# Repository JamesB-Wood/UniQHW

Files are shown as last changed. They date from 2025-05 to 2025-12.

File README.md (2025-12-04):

# UniQHW

The hardware repository for UQ Phone (UniQ)
The Corresponding software component can be found [https://github.com/Benksur/UniQOS](https://github.com/Benksur/UniQOS)

## About

**Supervised by:** Professor Pauline Pounds  
**Institution:** University of Queensland
<div align="center">

### UQ Phone Team (Year 1 - 2025)

| Name | Role |
|---|---|
| **Ty Behnke** | Firmware Design |
| **James Wood** | Hardware Design |
| **Caiyan Jin** | UI/UX Design |
</div>

Any Questions about the PCB and Schematics please direct them to [james.brian.wood@gmail.com](james.brian.wood@gmail.com)

## Production

The V0.2.0 PCB's must be made with the following specifications from JLCPCB

### Main PCB

This 6-Layer PCB must be made with the following

- Via Covering:	Epoxy Filled & Capped
- Min via hole size/diameter:	0.2mm/(0.3/0.35mm)

The following are also required if meeting the full size specifications of UniQ

- PCB Thickness:	0.8mm

Production versions should also be made with the following (Dependant on desired finish)

- Surface Finish:	ENIG Gold Thickness: 2U"
- PCB Color:	Black
- Silkscreen:	White

### Secondary PCB (Cellular Board)

This 4-Layer PCB must be made with the following

- PCB Thickness:	0.6mm
- Via Covering:	Epoxy Filled & Capped
- Min via hole size/diameter:	0.2mm/(0.3/0.35mm)
- Specify Stackup:	yes JLC04061H-2116

If Either the thickness or stackup is to change this boards traces should be redesigned for 50Ohm Impedance 

Production versions should also be made with the following (Dependant on desired finish)

- Surface Finish:	ENIG Gold Thickness: 2U"
- PCB Color:	Black
- Silkscreen:	White

## Current Issues And Improvements

The V0.2.0 PCB currently suffers from several issues which should be rectified on later versions:

- Batter Connector Location: move so it can be inserted and removed indpendantly of the secondary PCB
- SD/SIM Socket: Tie 3.3v SD card rail to insertion detection to prevent hot-plugging
- Debug Pads: Consider moving to provide easier access without interferance from screen
- Soft Power: Add soft power switch for more agressive power-off functionality and safer power-downs

The following may also be investigated for benefit 
- Improve Display: Ideally Display utilises a parellel interface, this needs more investigation
- Audio Volume: Current speaker is quiet, this should be investigated further to see if this can be remediated in firmware first
- USB Support: Add USB data connectivity to the device for file transfer or programming, this may resolve debug pad issues
- BT Audio: this poses significant challenges, although may be worth while, investigate further

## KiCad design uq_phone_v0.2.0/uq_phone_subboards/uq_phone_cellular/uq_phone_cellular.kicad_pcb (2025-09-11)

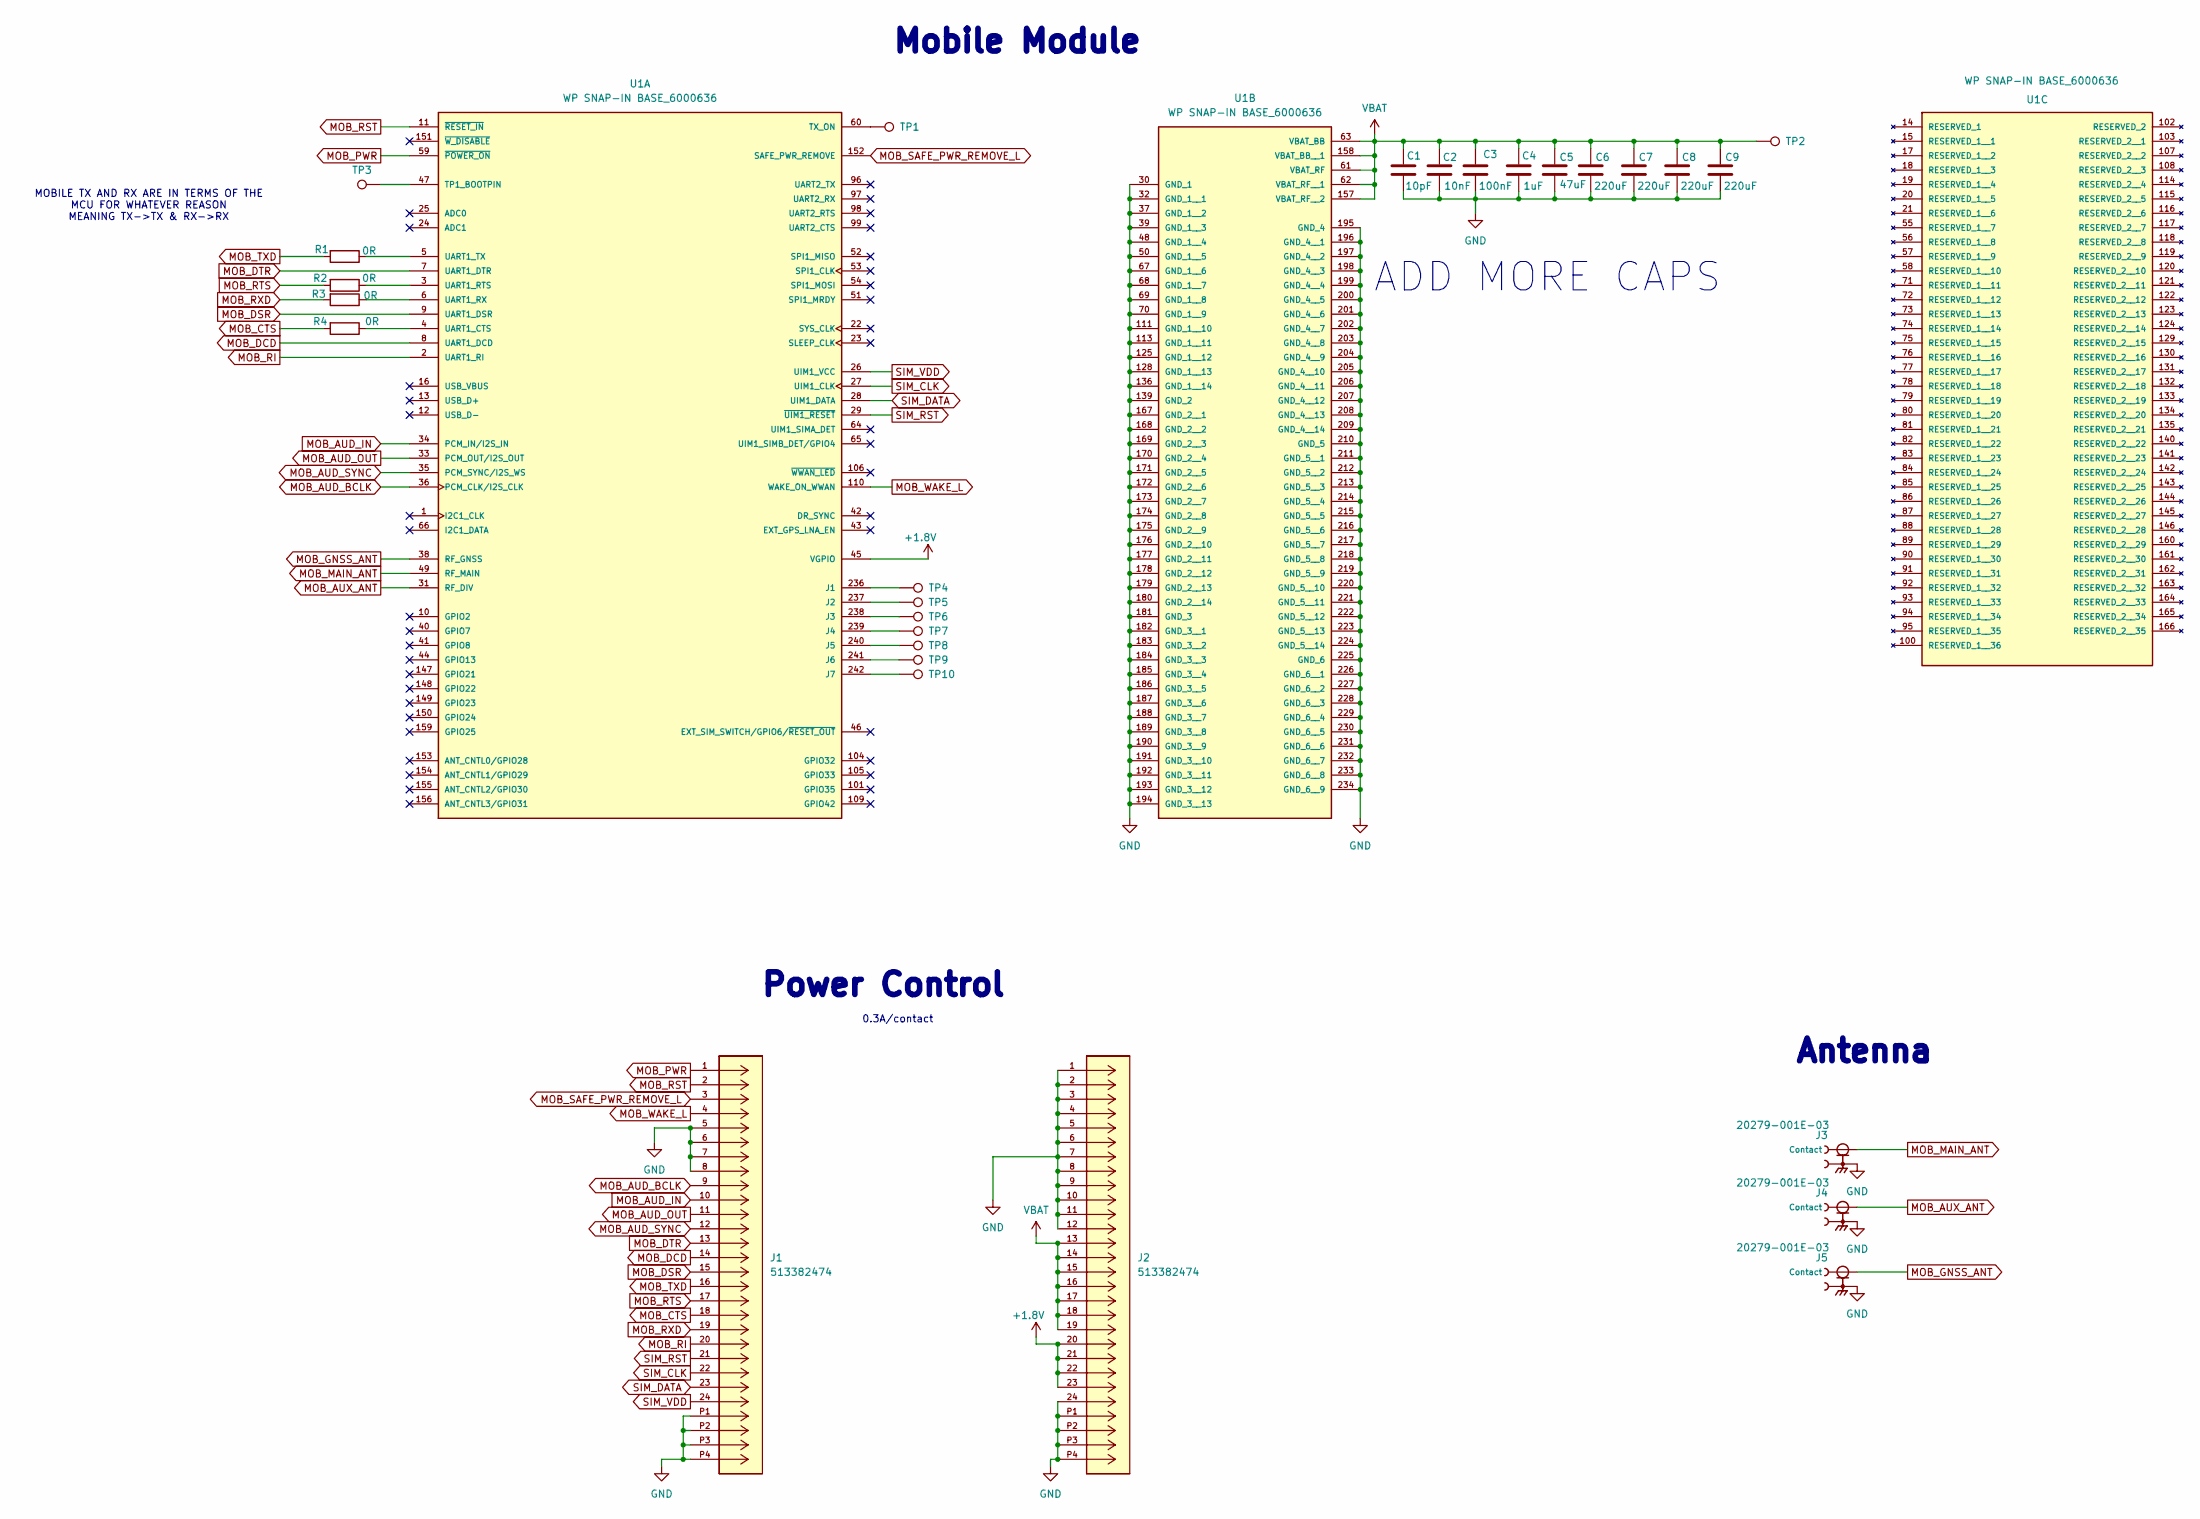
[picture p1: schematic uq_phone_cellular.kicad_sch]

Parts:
C1: 10pF; C_0402_1005Metric; LCSC PN C2168222
C2: 10nF; C_0402_1005Metric; LCSC PN C15195
C3: 100nF; C_0201_0603Metric; LCSC PN C160831
C4: 1uF; C_0201_0603Metric; LCSC PN C53067
C5: 47uF; C_0805_2012Metric; LCSC PN C109461
C6, C7, C8, C9: 220uF; C_1206_3216Metric; LCSC PN C412252
J1, J2: 513382474; CON_513382474; MANUFACTURER_PART_NUMBER 513382474; DigiKey_Part_Number WM8960TR-ND
J3, J4, J5: 20279-001E-03; IPEX_20279-001E-03; PARTREV 32; LCSC PN C36499136
R1, R2, R3, R4: 0R; R_0402_1005Metric; LCSC PN C60485
TP1, TP2, TP3, TP4, TP5, TP6, TP7, TP8, TP9, TP10: TestPoint; TestPoint_Pad_D1.5mm
U1: WP SNAP-IN BASE_6000636; XCVR_RC7620_1104625; PARTREV 12

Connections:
+1.8V: J2.20, J2.21, J2.22, J2.23, U1.45 (VGPIO)
GND: C1.2, C2.2, C3.2, C4.2, C5.2, C6.2, C7.2, C8.2, C9.2, J1.5, J1.6, J1.7, J1.8, J1.P1, J1.P2, J1.P3, J1.P4, J2.1, J2.2, J2.3, J2.4, J2.5, J2.6, J2.7, J2.8, J2.9, J2.10, J2.11, J2.12, J2.24, J2.P1, J2.P2, J2.P3, J2.P4, J3.2, J4.2, J5.2, U1.30 (GND_1), U1.32 (GND_1__1), U1.37 (GND_1__2), U1.39 (GND_1__3), U1.48 (GND_1__4), U1.50 (GND_1__5), U1.67 (GND_1__6), U1.68 (GND_1__7), U1.69 (GND_1__8), U1.70 (GND_1__9), U1.111 (GND_1__10), U1.113 (GND_1__11), U1.125 (GND_1__12), U1.128 (GND_1__13), U1.136 (GND_1__14), U1.139 (GND_2), U1.167 (GND_2__1), U1.168 (GND_2__2), U1.169 (GND_2__3), U1.170 (GND_2__4), U1.171 (GND_2__5), U1.172 (GND_2__6), U1.173 (GND_2__7), U1.174 (GND_2__8), U1.175 (GND_2__9), U1.176 (GND_2__10), U1.177 (GND_2__11), U1.178 (GND_2__12), U1.179 (GND_2__13), U1.180 (GND_2__14), U1.181 (GND_3), U1.182 (GND_3__1), U1.183 (GND_3__2), U1.184 (GND_3__3), U1.185 (GND_3__4), U1.186 (GND_3__5), U1.187 (GND_3__6), U1.188 (GND_3__7), U1.189 (GND_3__8), U1.190 (GND_3__9), U1.191 (GND_3__10), U1.192 (GND_3__11), U1.193 (GND_3__12), U1.194 (GND_3__13), U1.195 (GND_4), U1.196 (GND_4__1), U1.197 (GND_4__2), U1.198 (GND_4__3), U1.199 (GND_4__4), U1.200 (GND_4__5), U1.201 (GND_4__6), U1.202 (GND_4__7), U1.203 (GND_4__8), U1.204 (GND_4__9), U1.205 (GND_4__10), U1.206 (GND_4__11), U1.207 (GND_4__12), U1.208 (GND_4__13), U1.209 (GND_4__14), U1.210 (GND_5), U1.211 (GND_5__1), U1.212 (GND_5__2), U1.213 (GND_5__3), U1.214 (GND_5__4), U1.215 (GND_5__5), U1.216 (GND_5__6), U1.217 (GND_5__7), U1.218 (GND_5__8), U1.219 (GND_5__9), U1.220 (GND_5__10), U1.221 (GND_5__11), U1.222 (GND_5__12), U1.223 (GND_5__13), U1.224 (GND_5__14), U1.225 (GND_6), U1.226 (GND_6__1), U1.227 (GND_6__2), U1.228 (GND_6__3), U1.229 (GND_6__4), U1.230 (GND_6__5), U1.231 (GND_6__6), U1.232 (GND_6__7), U1.233 (GND_6__8), U1.234 (GND_6__9)
MOB_AUD_BCLK: J1.9, U1.36 (PCM_CLK/I2S_CLK)
MOB_AUD_IN: J1.10, U1.34 (PCM_IN/I2S_IN)
MOB_AUD_OUT: J1.11, U1.33 (PCM_OUT/I2S_OUT)
MOB_AUD_SYNC: J1.12, U1.35 (PCM_SYNC/I2S_WS)
MOB_AUX_ANT: J4.1 (Contact), U1.31 (RF_DIV)
MOB_CTS: J1.18, R4.2
MOB_DCD: J1.14, U1.8 (UART1_DCD)
MOB_DSR: J1.15, U1.9 (UART1_DSR)
MOB_DTR: J1.13, U1.7 (UART1_DTR)
MOB_GNSS_ANT: J5.1 (Contact), U1.38 (RF_GNSS)
MOB_MAIN_ANT: J3.1 (Contact), U1.49 (RF_MAIN)
MOB_PWR: J1.1, U1.59 (~POWER_ON)
MOB_RI: J1.20, U1.2 (UART1_RI)
MOB_RST: J1.2, U1.11 (~RESET_IN)
MOB_RTS: J1.17, R2.2
MOB_RXD: J1.19, R3.2
MOB_SAFE_PWR_REMOVE_L: J1.3, U1.152 (SAFE_PWR_REMOVE)
MOB_TXD: J1.16, R1.2
MOB_WAKE_L: J1.4, U1.110 (WAKE_ON_WWAN)
unnamed: TP4.1, U1.236 (J1)
unnamed: TP5.1, U1.237 (J2)
unnamed: TP6.1, U1.238 (J3)
unnamed: TP7.1, U1.239 (J4)
unnamed: TP8.1, U1.240 (J5)
unnamed: TP9.1, U1.241 (J6)
unnamed: TP10.1, U1.242 (J7)
unnamed: TP3.1, U1.47 (TP1_BOOTPIN)
unnamed: TP1.1, U1.60 (TX_ON)
unnamed: R4.1, U1.4 (UART1_CTS)
unnamed: R2.1, U1.3 (UART1_RTS)
unnamed: R3.1, U1.6 (UART1_RX)
unnamed: R1.1, U1.5 (UART1_TX)
SIM_CLK: J1.22, U1.27 (UIM1_CLK)
SIM_DATA: J1.23, U1.28 (UIM1_DATA)
SIM_RST: J1.21, U1.29 (~UIM1_RESET)
SIM_VDD: J1.24, U1.26 (UIM1_VCC)
VBAT: C1.1, C2.1, C3.1, C4.1, C5.1, C6.1, C7.1, C8.1, C9.1, J2.13, J2.14, J2.15, J2.16, J2.17, J2.18, J2.19, TP2.1, U1.61 (VBAT_RF), U1.62 (VBAT_RF__1), U1.63 (VBAT_BB), U1.157 (VBAT_RF__2), U1.158 (VBAT_BB__1)

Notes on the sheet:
ADD MORE CAPS
Antenna
Power Control
MOBILE TX AND RX ARE IN TERMS OF THE MCU FOR WHATEVER REASON MEANING TX->TX & RX->RX
0.3A/contact
Mobile Module

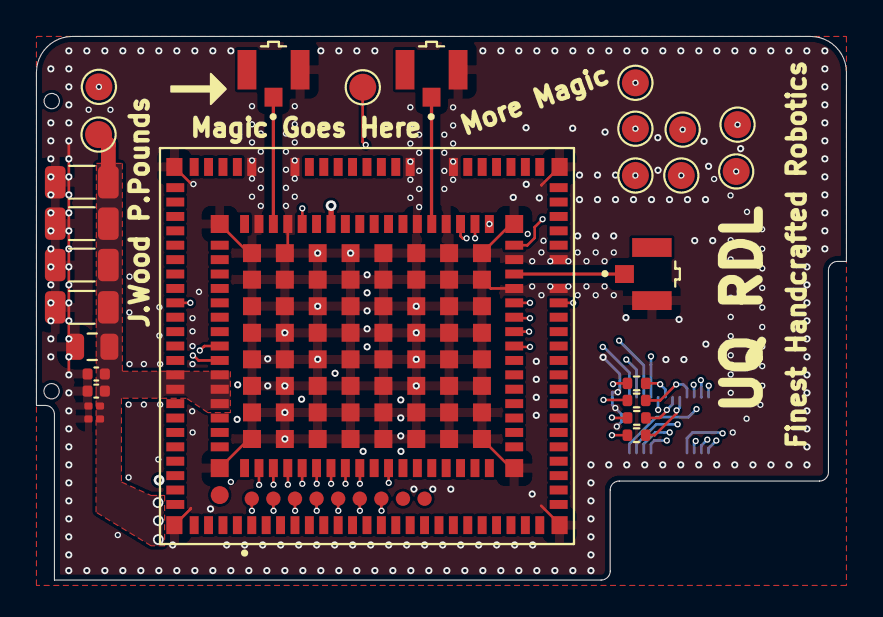
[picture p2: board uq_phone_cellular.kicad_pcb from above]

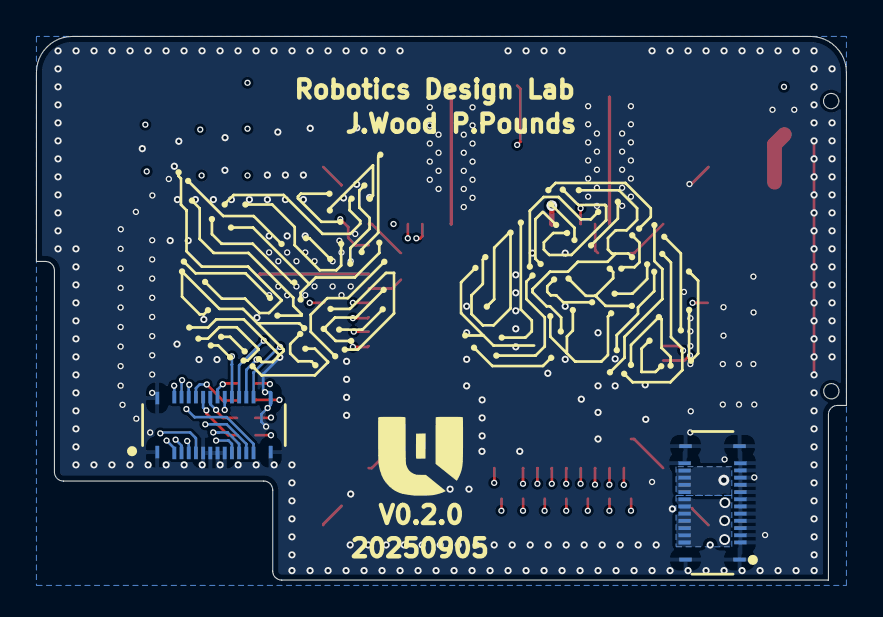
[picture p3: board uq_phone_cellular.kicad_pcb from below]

Board: 4 copper layers, 45.0 x 30.2 mm, 29 parts (2 on the bottom side), 39 nets.

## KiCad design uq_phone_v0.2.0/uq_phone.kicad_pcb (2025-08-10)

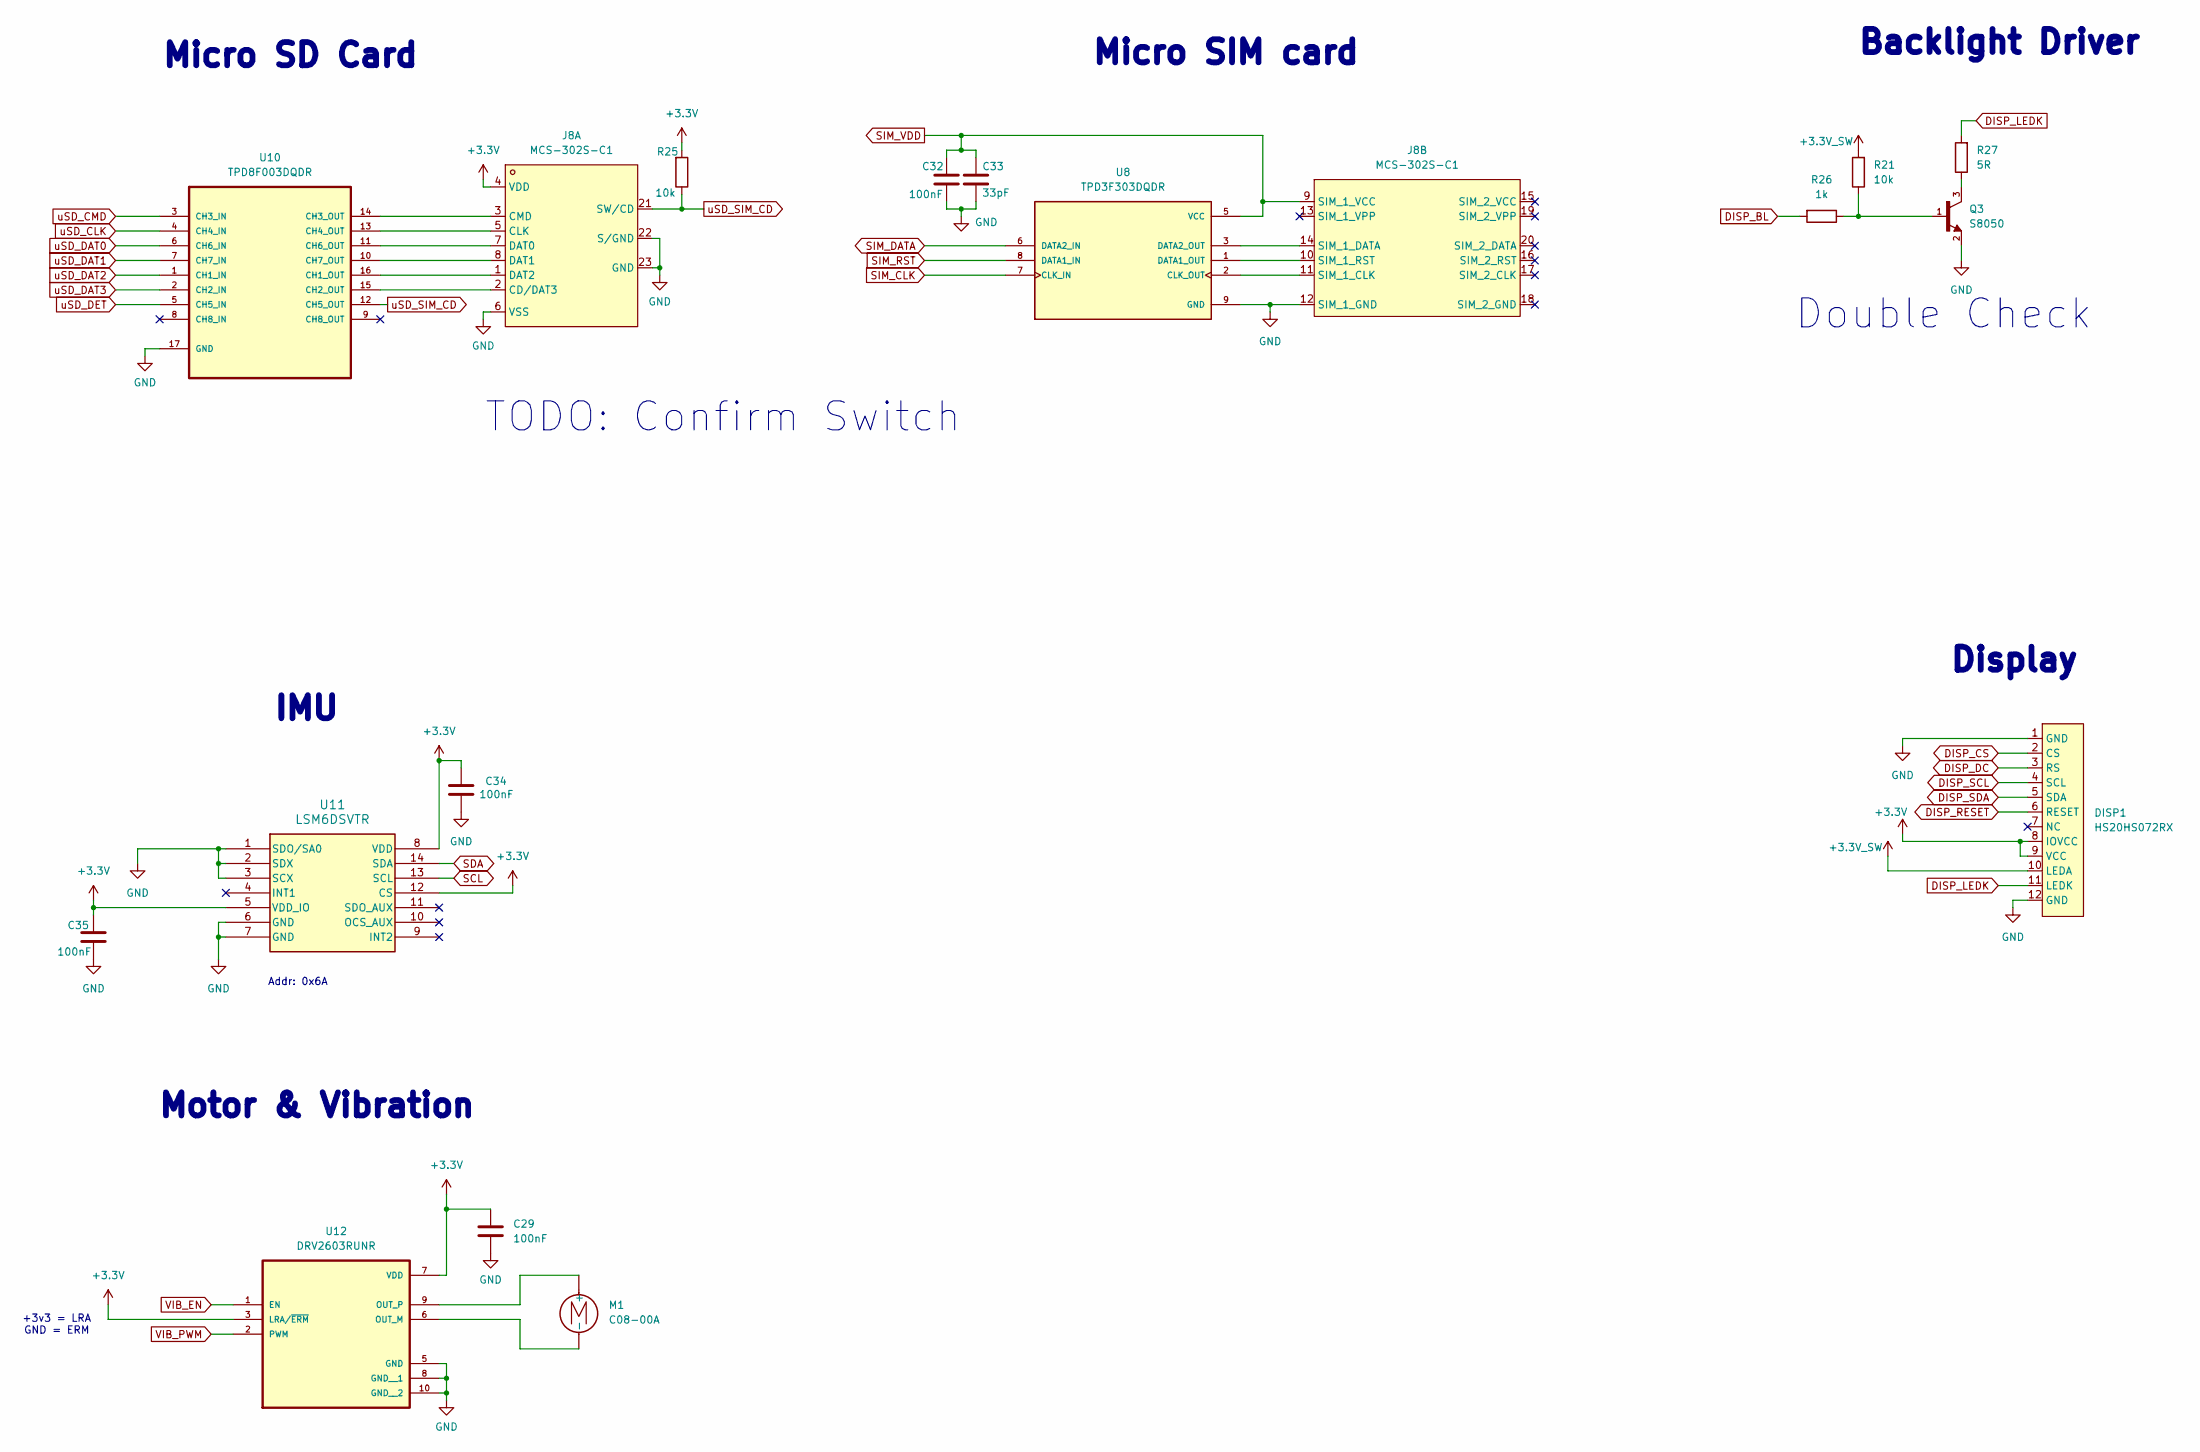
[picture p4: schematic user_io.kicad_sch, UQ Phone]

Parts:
C29, C32, C34, C35: 100nF; C_0201_0603Metric; LCSC PN C160831
C33: 33pF; C_0402_1005Metric; LCSC PN C70465
DISP1: HS20HS072RX; Display
J8: MCS-302S-C1; SIM-SMD_MCS-302S-C1; Manufacturer Part MCS-302S-C1; LCSC Part Name 卡托式 NanoSIM卡 卡座
M1: C08-00A; Motor_8mm
Q3: S8050; SOT-23; LCSC PN C916390
R21, R25: 10k; R_0201_0603Metric; LCSC PN C106225
R26: 1k; R_0402_1005Metric; LCSC PN C5455561
R27: 5R; R_0402_1005Metric; LCSC PN C25128
U8: TPD3F303DQDR; SON40P170X135X80-9N; PARTREV A; DigiKey_Part_Number 296-28300-2-ND
U10: TPD8F003DQDR; SON40P135X330X80-17N; MPN TPD8F003DQDR; DigiKey_Part_Number 296-25803-2-ND
U11: LSM6DSVTR; LGA14-L_2P59X3P1X0P5_STM
U12: DRV2603RUNR; QFN50P200X200X80-10N; PARTREV C; DigiKey_Part_Number 296-30613-2-ND

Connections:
+3.3V: C29.1, C34.1, C35.1, DISP1.8 (IOVCC), DISP1.9 (VCC), J8.4 (VDD), R25.2, U11.5 (VDD_IO), U11.8 (VDD), U11.12 (CS), U12.3 (LRA/~ERM), U12.7 (VDD); also elsewhere on the board
+3.3V_SW: DISP1.10 (LEDA), R21.2; also elsewhere on the board
DISP_BL: R26.2; also elsewhere on the board
DISP_CS: DISP1.2 (CS); also elsewhere on the board
DISP_DC: DISP1.3 (RS); also elsewhere on the board
DISP_LEDK: DISP1.11 (LEDK), R27.2
DISP_RESET: DISP1.6 (RESET); also elsewhere on the board
DISP_SCL: DISP1.4 (SCL); also elsewhere on the board
DISP_SDA: DISP1.5 (SDA); also elsewhere on the board
GND: C29.2, C32.2, C33.2, C34.2, C35.2, DISP1.1 (GND), DISP1.12 (GND), J8.6 (VSS), J8.12 (SIM_1_GND), J8.22 (S/GND), J8.23 (GND), Q3.2, U8.9 (GND), U10.17 (GND), U11.1 (SDO/SA0), U11.2 (SDX), U11.3 (SCX), U11.6 (GND), U11.7 (GND), U12.5 (GND), U12.8 (GND__1), U12.10 (GND__2); also elsewhere on the board
unnamed: J8.2 (CD/DAT3), U10.15 (CH2_OUT)
unnamed: J8.5 (CLK), U10.13 (CH4_OUT)
unnamed: J8.3 (CMD), U10.14 (CH3_OUT)
unnamed: J8.7 (DAT0), U10.11 (CH6_OUT)
unnamed: J8.8 (DAT1), U10.10 (CH7_OUT)
unnamed: J8.1 (DAT2), U10.16 (CH1_OUT)
unnamed: J8.11 (SIM_1_CLK), U8.2 (CLK_OUT)
unnamed: J8.14 (SIM_1_DATA), U8.3 (DATA2_OUT)
unnamed: J8.10 (SIM_1_RST), U8.1 (DATA1_OUT)
unnamed: M1.1 (+), U12.9 (OUT_P)
unnamed: M1.2 (-), U12.6 (OUT_M)
unnamed: Q3.1, R21.1, R26.1
unnamed: Q3.3, R27.1
SCL: U11.13 (SCL); also elsewhere on the board
SDA: U11.14 (SDA); also elsewhere on the board
SIM_CLK: U8.7 (CLK_IN); also elsewhere on the board
SIM_DATA: U8.6 (DATA2_IN); also elsewhere on the board
SIM_RST: U8.8 (DATA1_IN); also elsewhere on the board
SIM_VDD: C32.1, C33.1, J8.9 (SIM_1_VCC), U8.5 (VCC); also elsewhere on the board
VIB_EN: U12.1 (EN); also elsewhere on the board
VIB_PWM: U12.2 (PWM); also elsewhere on the board
uSD_CLK: U10.4 (CH4_IN); also elsewhere on the board
uSD_CMD: U10.3 (CH3_IN); also elsewhere on the board
uSD_DAT0: U10.6 (CH6_IN); also elsewhere on the board
uSD_DAT1: U10.7 (CH7_IN); also elsewhere on the board
uSD_DAT2: U10.1 (CH1_IN); also elsewhere on the board
uSD_DAT3: U10.2 (CH2_IN); also elsewhere on the board
uSD_DET: U10.5 (CH5_IN); also elsewhere on the board
uSD_SIM_CD: J8.21 (SW/CD), R25.1, U10.12 (CH5_OUT)

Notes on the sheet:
Motor & Vibration
Display
IMU
Backlight Driver
Double Check
Micro SIM card
TODO: Confirm Switch
Micro SD Card
+3v3 = LRA GND = ERM
Addr: 0x6A

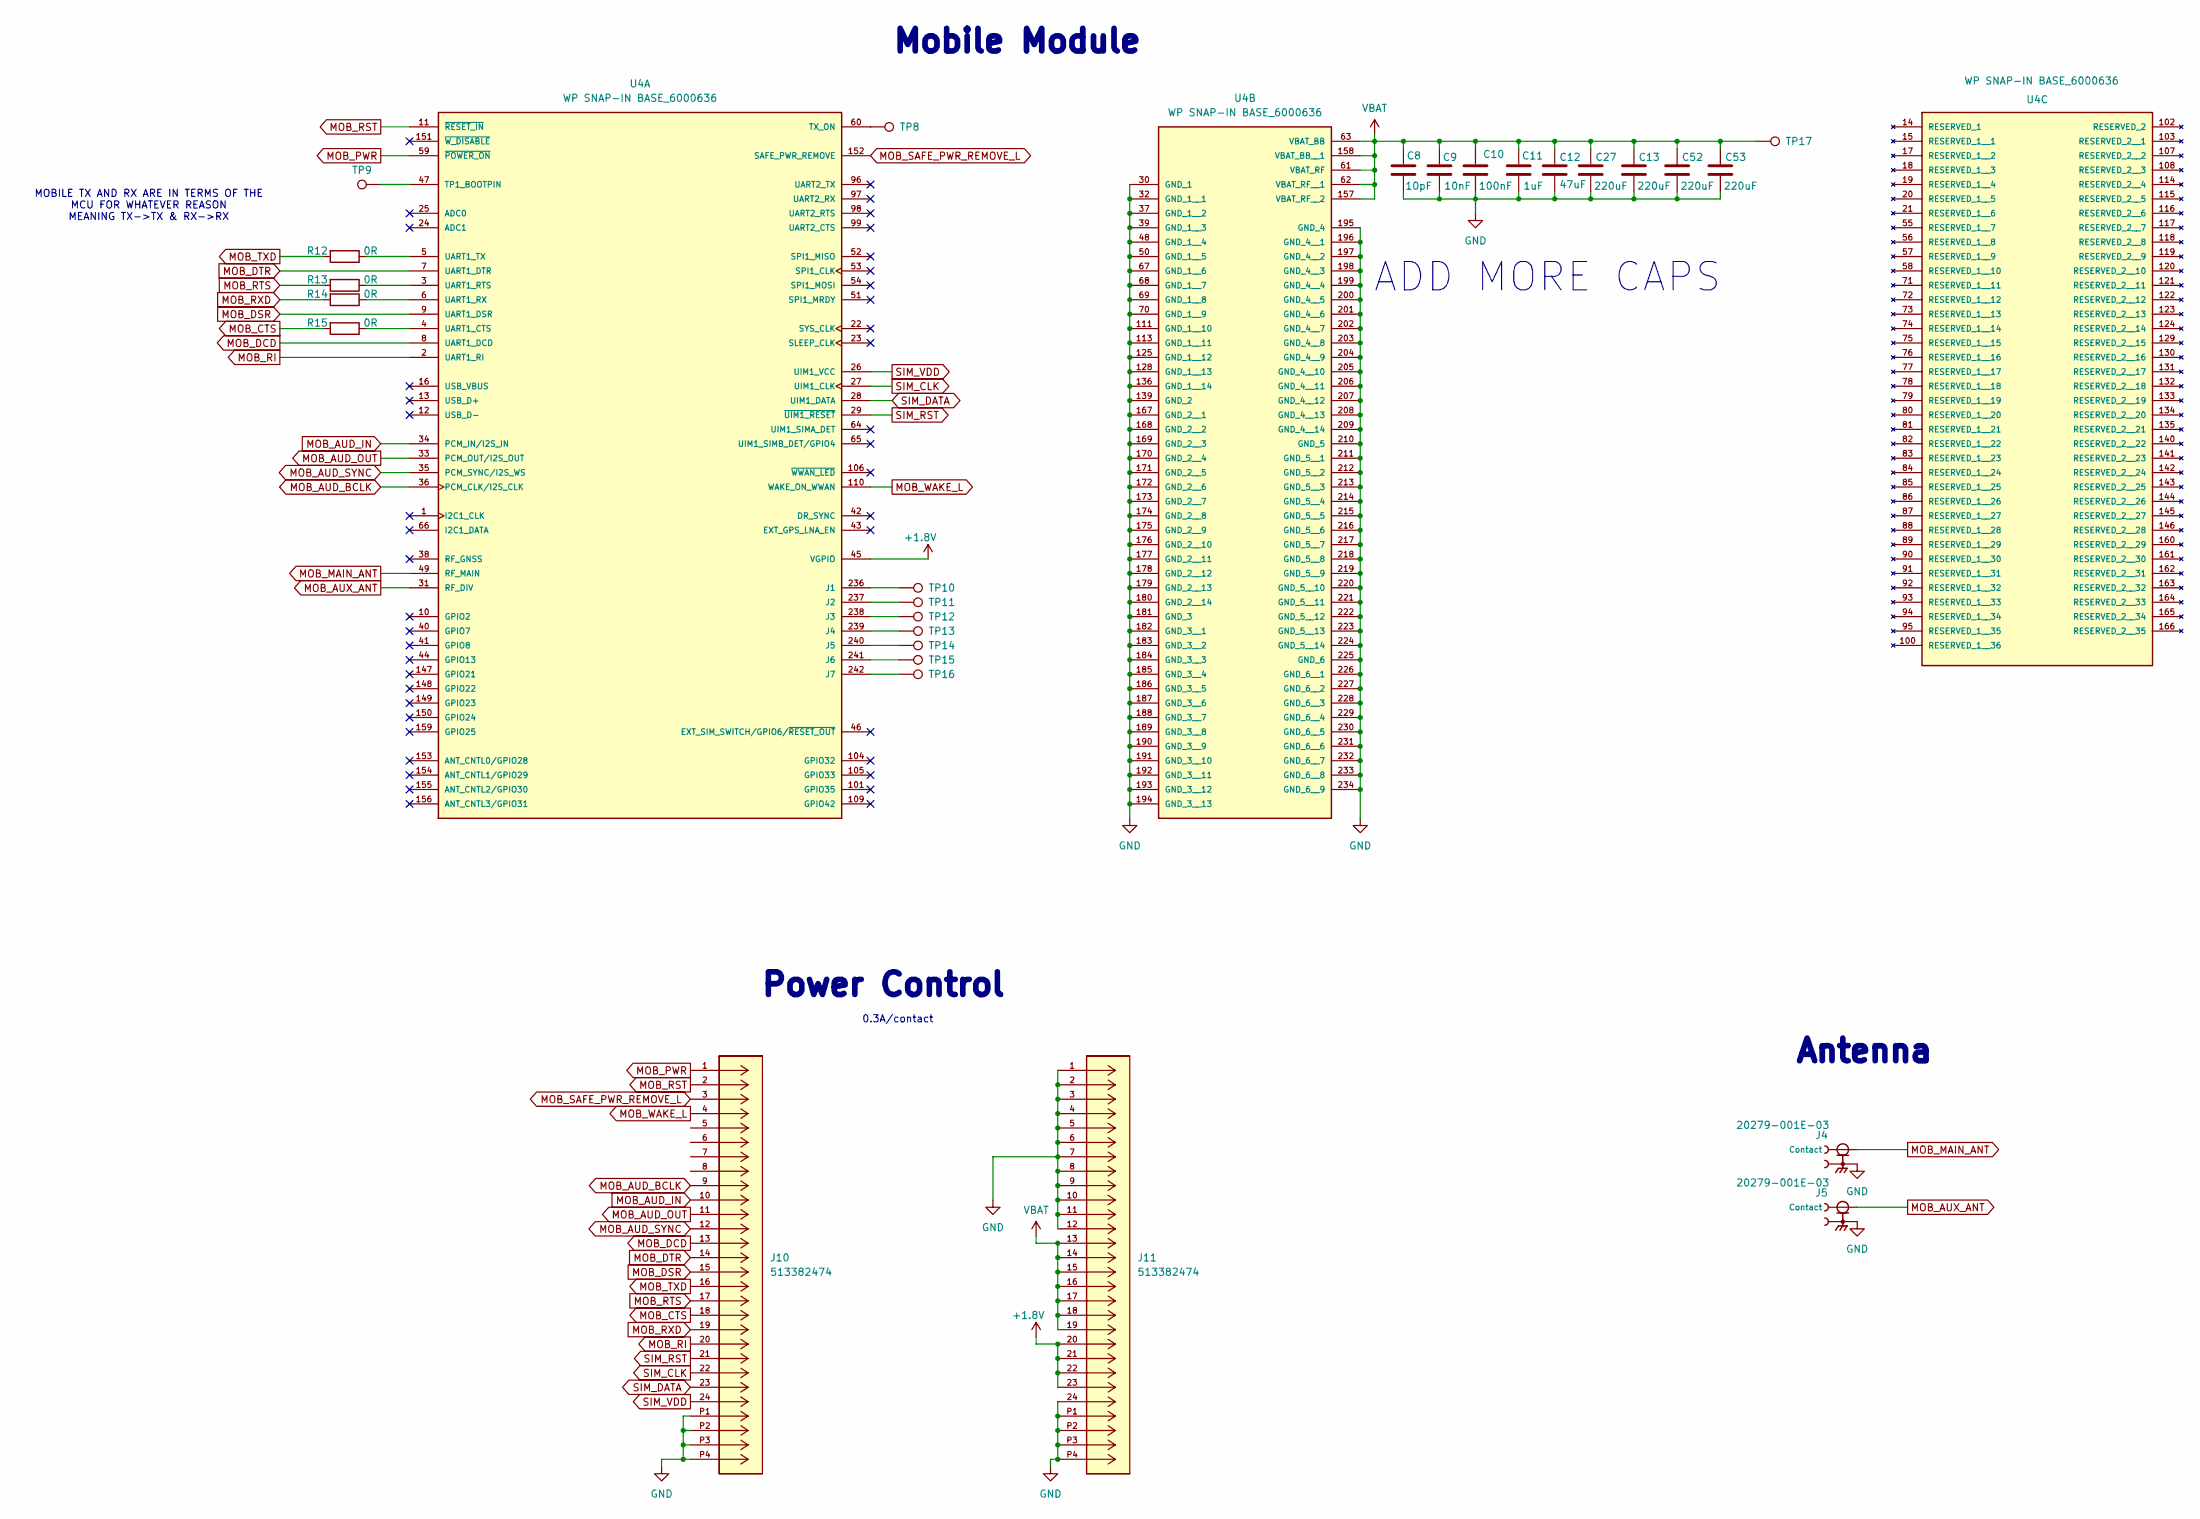
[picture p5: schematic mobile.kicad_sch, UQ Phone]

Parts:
C8: 10pF; C_0402_1005Metric; LCSC PN C2168222
C9: 10nF; C_0402_1005Metric; LCSC PN C15195
C10: 100nF; C_0201_0603Metric; LCSC PN C160831
C11: 1uF; C_0201_0603Metric; LCSC PN C53067
C12: 47uF; C_0805_2012Metric; LCSC PN C109461
C13, C27, C52, C53: 220uF; C_1206_3216Metric; LCSC PN C412252
J4, J5: 20279-001E-03; IPEX_20279-001E-03; PARTREV 32; LCSC PN C36499136
J10, J11: 513382474; CON_513382474; MANUFACTURER_PART_NUMBER 513382474; DigiKey_Part_Number WM8960TR-ND
R12, R13, R14, R15: 0R; R_0402_1005Metric
TP8, TP9, TP10, TP11, TP12, TP13, TP14, TP15, TP16, TP17: TestPoint; TestPoint_Pad_D1.5mm
U4: WP SNAP-IN BASE_6000636; XCVR_RC7620_1104625; PARTREV 12

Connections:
+1.8V: J11.20, J11.21, J11.22, J11.23, U4.45 (VGPIO); also elsewhere on the board
GND: C8.2, C9.2, C10.2, C11.2, C12.2, C13.2, C27.2, C52.2, C53.2, J4.2, J5.2, J10.P1, J10.P2, J10.P3, J10.P4, J11.1, J11.2, J11.3, J11.4, J11.5, J11.6, J11.7, J11.8, J11.9, J11.10, J11.11, J11.12, J11.24, J11.P1, J11.P2, J11.P3, J11.P4, U4.30 (GND_1), U4.32 (GND_1__1), U4.37 (GND_1__2), U4.39 (GND_1__3), U4.48 (GND_1__4), U4.50 (GND_1__5), U4.67 (GND_1__6), U4.68 (GND_1__7), U4.69 (GND_1__8), U4.70 (GND_1__9), U4.111 (GND_1__10), U4.113 (GND_1__11), U4.125 (GND_1__12), U4.128 (GND_1__13), U4.136 (GND_1__14), U4.139 (GND_2), U4.167 (GND_2__1), U4.168 (GND_2__2), U4.169 (GND_2__3), U4.170 (GND_2__4), U4.171 (GND_2__5), U4.172 (GND_2__6), U4.173 (GND_2__7), U4.174 (GND_2__8), U4.175 (GND_2__9), U4.176 (GND_2__10), U4.177 (GND_2__11), U4.178 (GND_2__12), U4.179 (GND_2__13), U4.180 (GND_2__14), U4.181 (GND_3), U4.182 (GND_3__1), U4.183 (GND_3__2), U4.184 (GND_3__3), U4.185 (GND_3__4), U4.186 (GND_3__5), U4.187 (GND_3__6), U4.188 (GND_3__7), U4.189 (GND_3__8), U4.190 (GND_3__9), U4.191 (GND_3__10), U4.192 (GND_3__11), U4.193 (GND_3__12), U4.194 (GND_3__13), U4.195 (GND_4), U4.196 (GND_4__1), U4.197 (GND_4__2), U4.198 (GND_4__3), U4.199 (GND_4__4), U4.200 (GND_4__5), U4.201 (GND_4__6), U4.202 (GND_4__7), U4.203 (GND_4__8), U4.204 (GND_4__9), U4.205 (GND_4__10), U4.206 (GND_4__11), U4.207 (GND_4__12), U4.208 (GND_4__13), U4.209 (GND_4__14), U4.210 (GND_5), U4.211 (GND_5__1), U4.212 (GND_5__2), U4.213 (GND_5__3), U4.214 (GND_5__4), U4.215 (GND_5__5), U4.216 (GND_5__6), U4.217 (GND_5__7), U4.218 (GND_5__8), U4.219 (GND_5__9), U4.220 (GND_5__10), U4.221 (GND_5__11), U4.222 (GND_5__12), U4.223 (GND_5__13), U4.224 (GND_5__14), U4.225 (GND_6), U4.226 (GND_6__1), U4.227 (GND_6__2), U4.228 (GND_6__3), U4.229 (GND_6__4), U4.230 (GND_6__5), U4.231 (GND_6__6), U4.232 (GND_6__7), U4.233 (GND_6__8), U4.234 (GND_6__9); also elsewhere on the board
MOB_AUD_BCLK: J10.9, U4.36 (PCM_CLK/I2S_CLK); also elsewhere on the board
MOB_AUD_IN: J10.10, U4.34 (PCM_IN/I2S_IN); also elsewhere on the board
MOB_AUD_OUT: J10.11, U4.33 (PCM_OUT/I2S_OUT); also elsewhere on the board
MOB_AUD_SYNC: J10.12, U4.35 (PCM_SYNC/I2S_WS); also elsewhere on the board
MOB_AUX_ANT: J5.1 (Contact), U4.31 (RF_DIV)
MOB_CTS: J10.18, R15.2; also elsewhere on the board
MOB_DCD: J10.13, U4.8 (UART1_DCD); also elsewhere on the board
MOB_DSR: J10.15, U4.9 (UART1_DSR); also elsewhere on the board
MOB_DTR: J10.14, U4.7 (UART1_DTR); also elsewhere on the board
MOB_MAIN_ANT: J4.1 (Contact), U4.49 (RF_MAIN)
MOB_PWR: J10.1, U4.59 (~POWER_ON); also elsewhere on the board
MOB_RI: J10.20, U4.2 (UART1_RI); also elsewhere on the board
MOB_RST: J10.2, U4.11 (~RESET_IN); also elsewhere on the board
MOB_RTS: J10.17, R13.2; also elsewhere on the board
MOB_RXD: J10.19, R14.2; also elsewhere on the board
MOB_SAFE_PWR_REMOVE_L: J10.3, U4.152 (SAFE_PWR_REMOVE); also elsewhere on the board
MOB_TXD: J10.16, R12.2; also elsewhere on the board
MOB_WAKE_L: J10.4, U4.110 (WAKE_ON_WWAN); also elsewhere on the board
unnamed: TP10.1, U4.236 (J1)
unnamed: TP11.1, U4.237 (J2)
unnamed: TP12.1, U4.238 (J3)
unnamed: TP13.1, U4.239 (J4)
unnamed: TP14.1, U4.240 (J5)
unnamed: TP15.1, U4.241 (J6)
unnamed: TP16.1, U4.242 (J7)
unnamed: TP9.1, U4.47 (TP1_BOOTPIN)
unnamed: TP8.1, U4.60 (TX_ON)
unnamed: R15.1, U4.4 (UART1_CTS)
unnamed: R13.1, U4.3 (UART1_RTS)
unnamed: R14.1, U4.6 (UART1_RX)
unnamed: R12.1, U4.5 (UART1_TX)
SIM_CLK: J10.22, U4.27 (UIM1_CLK); also elsewhere on the board
SIM_DATA: J10.23, U4.28 (UIM1_DATA); also elsewhere on the board
SIM_RST: J10.21, U4.29 (~UIM1_RESET); also elsewhere on the board
SIM_VDD: J10.24, U4.26 (UIM1_VCC); also elsewhere on the board
VBAT: C8.1, C9.1, C10.1, C11.1, C12.1, C13.1, C27.1, C52.1, C53.1, J11.13, J11.14, J11.15, J11.16, J11.17, J11.18, J11.19, TP17.1, U4.61 (VBAT_RF), U4.62 (VBAT_RF__1), U4.63 (VBAT_BB), U4.157 (VBAT_RF__2), U4.158 (VBAT_BB__1); also elsewhere on the board

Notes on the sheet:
Power Control
Mobile Module
MOBILE TX AND RX ARE IN TERMS OF THE MCU FOR WHATEVER REASON MEANING TX->TX & RX->RX
ADD MORE CAPS
0.3A/contact
Antenna

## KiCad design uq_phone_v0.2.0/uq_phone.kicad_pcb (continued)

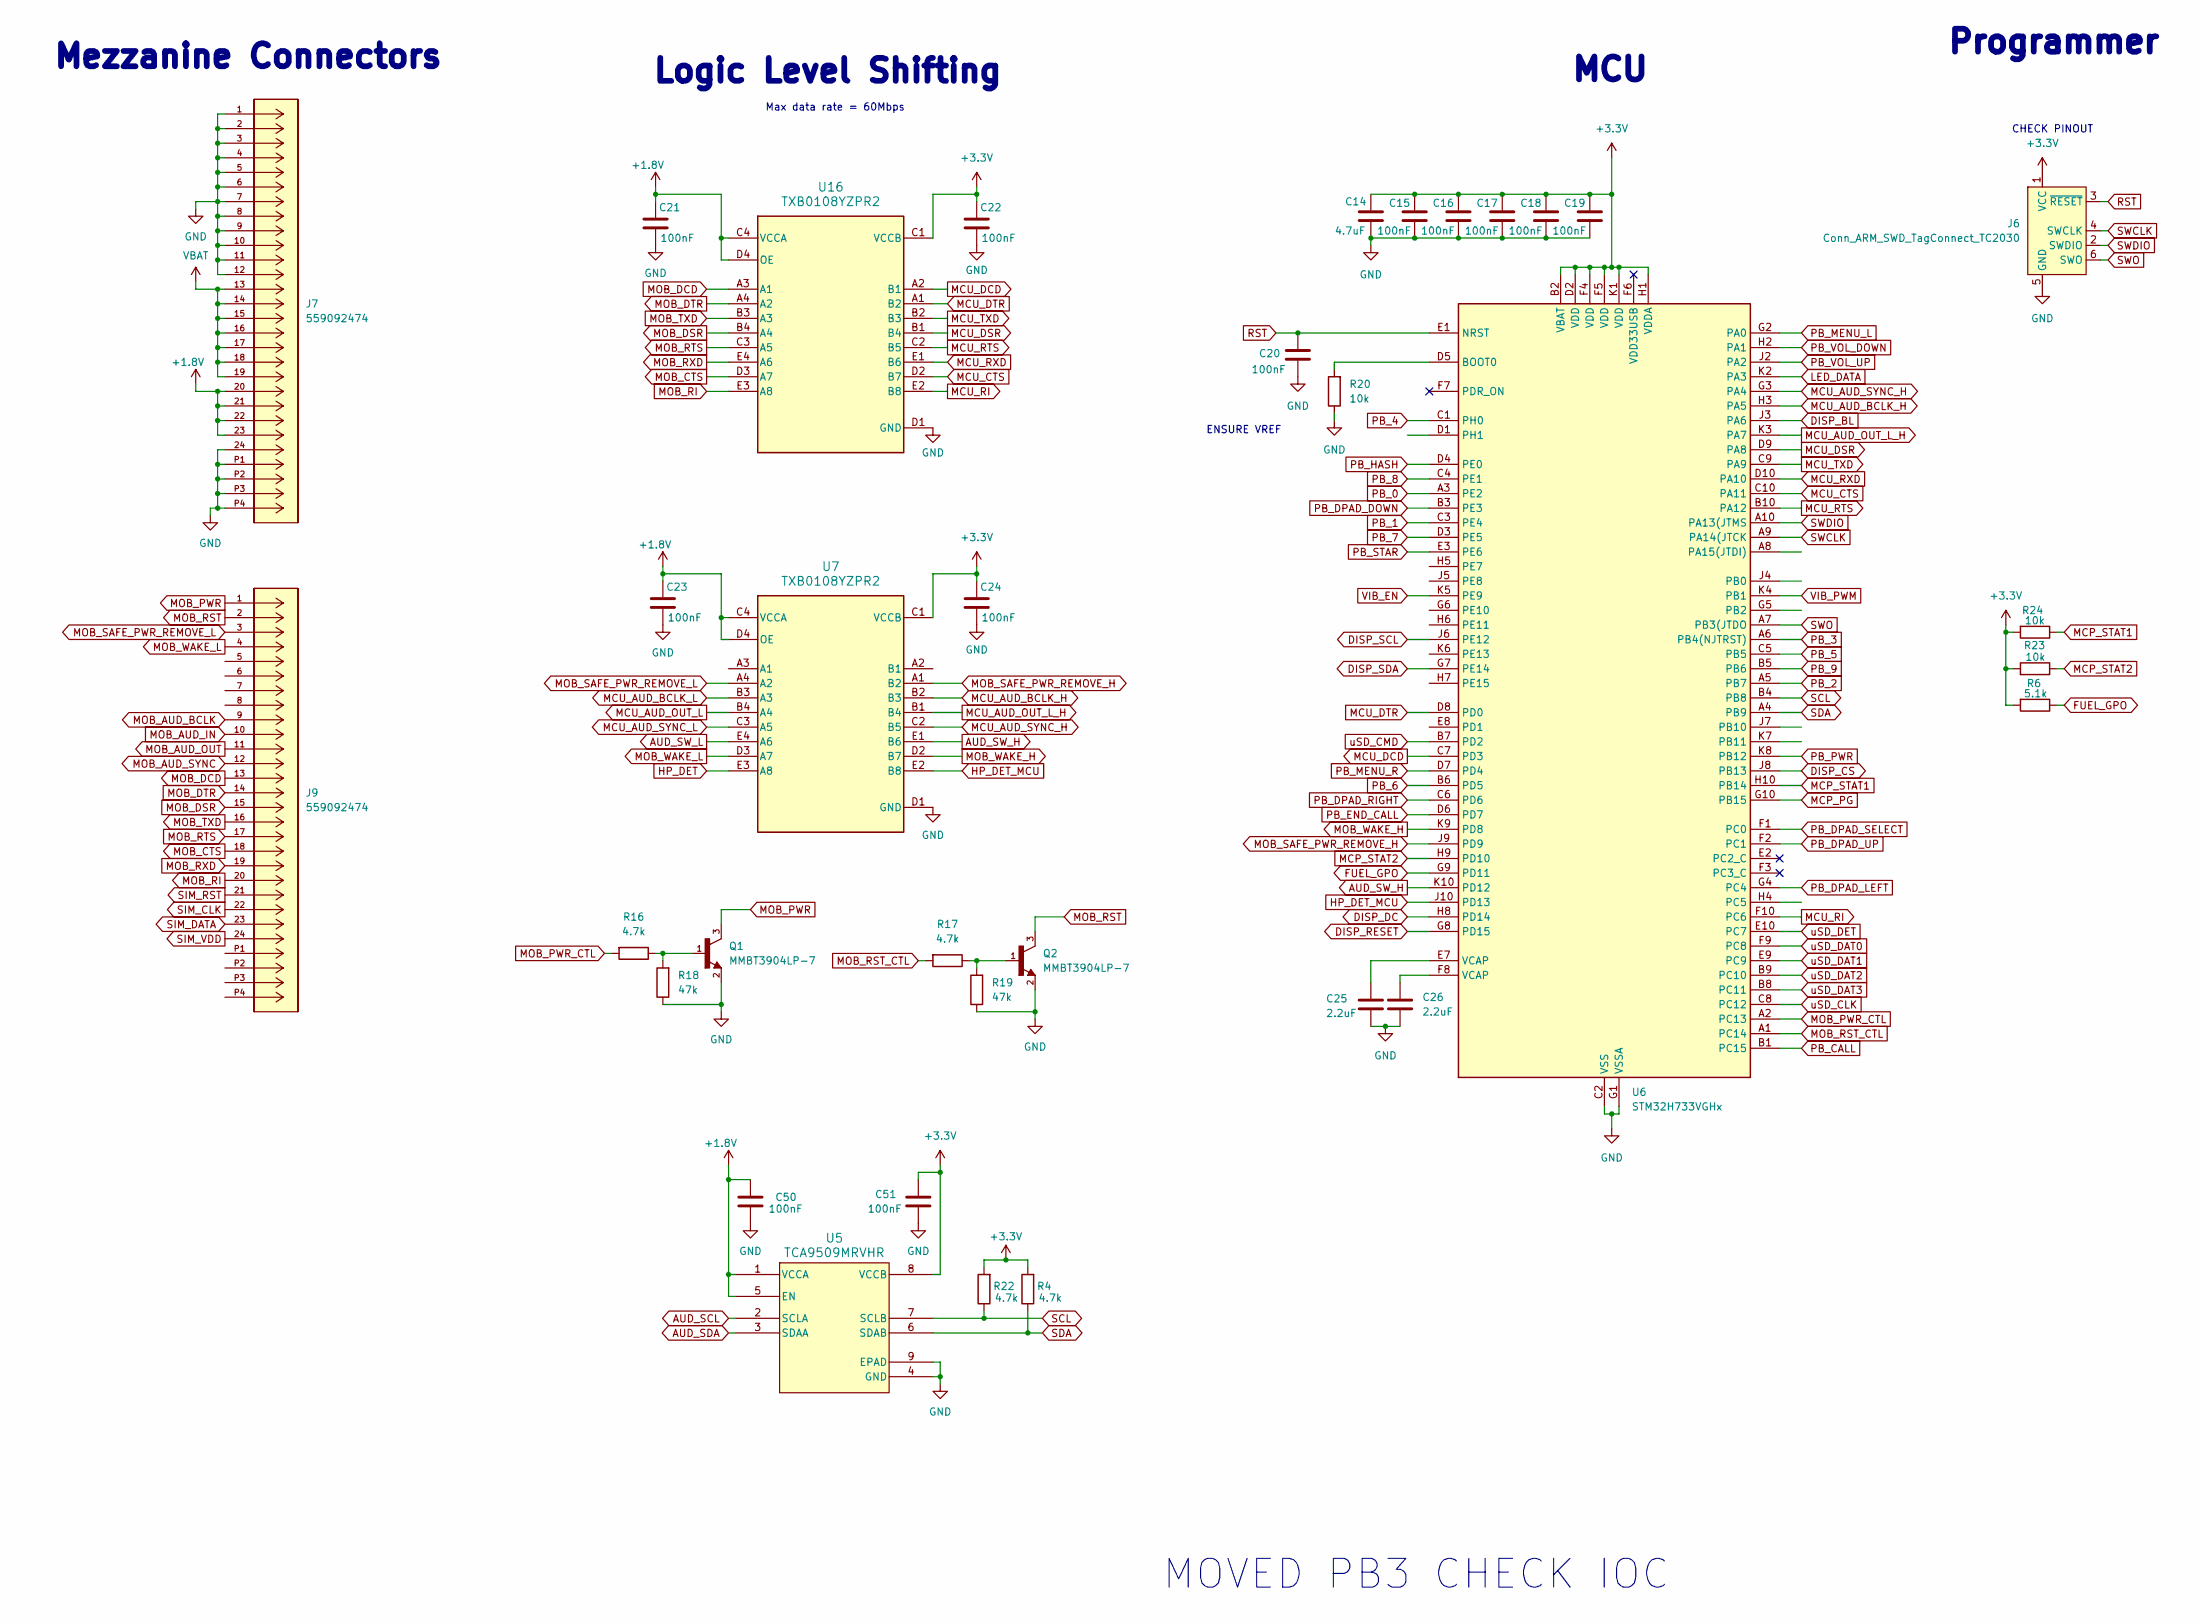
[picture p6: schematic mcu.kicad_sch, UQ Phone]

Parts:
C14: 4.7uF; C_0201_0603Metric; LCSC PN C335103
C15, C16, C17, C18, C19, C20, C21, C22, C23, C24, C50, C51: 100nF; C_0201_0603Metric; LCSC PN C160831
C25, C26: 2.2uF; C_0402_1005Metric; LCSC PN C107369
J6: Conn_ARM_SWD_TagConnect_TC2030; Tag-Connect_TC2030-IDC-FP_2x03_P1.27mm_Vertical
J7, J9: 559092474; CON_559092474; MANUFACTURER_PART_NUMBER 559092474; DigiKey_Part_Number WM3787TR-ND
Q1, Q2: MMBT3904LP-7; DFN101X61X53-3N; DigiKey_Part_Number MMBT3904LP-7DITR-ND
R4, R16, R17, R22: 4.7k; R_0201_0603Metric; LCSC PN C138135
R6: 5.1k; R_0201_0603Metric; LCSC PN C274341
R18, R19: 47k; R_0201_0603Metric; LCSC PN C138139
R20, R23, R24: 10k; R_0201_0603Metric; LCSC PN C106225
U5: TCA9509MRVHR; RVH8_0P4X0P4; LCSC PN C2652478
U6: STM32H733VGHx; TFBGA-100_8x8mm_Layout10x10_P0.8mm
U7, U16: TXB0108YZPR2; YZP20

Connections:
+1.8V: C21.1, C23.1, C50.1, J7.20, J7.21, J7.22, J7.23, U5.1 (VCCA), U5.5 (EN), U7.C4 (VCCA), U7.D4 (OE), U16.C4 (VCCA), U16.D4 (OE); also elsewhere on the board
+3.3V: C14.1, C15.2, C16.2, C17.2, C18.2, C19.2, C22.1, C24.1, C51.1, J6.1 (VCC), R4.2, R6.2, R22.2, R23.2, R24.2, U5.8 (VCCB), U6.B2 (VBAT), U6.D2 (VDD), U6.F4 (VDD), U6.F5 (VDD), U6.H1 (VDDA), U6.K1 (VDD), U7.C1 (VCCB), U16.C1 (VCCB); also elsewhere on the board
AUD_SCL: U5.2 (SCLA); also elsewhere on the board
AUD_SDA: U5.3 (SDAA); also elsewhere on the board
AUD_SW_H: U6.K10 (PD12), U7.E1 (B6)
AUD_SW_L: U7.E4 (A6); also elsewhere on the board
DISP_BL: U6.J3 (PA6); also elsewhere on the board
DISP_CS: U6.J8 (PB13); also elsewhere on the board
DISP_DC: U6.H8 (PD14); also elsewhere on the board
DISP_RESET: U6.G8 (PD15); also elsewhere on the board
DISP_SCL: U6.J6 (PE12); also elsewhere on the board
DISP_SDA: U6.G7 (PE14); also elsewhere on the board
FUEL_GPO: R6.1, U6.G9 (PD11); also elsewhere on the board
GND: C14.2, C15.1, C16.1, C17.1, C18.1, C19.1, C20.1, C21.2, C22.2, C23.2, C24.2, C25.2, C26.2, C50.2, C51.2, J6.5 (GND), J7.1, J7.2, J7.3, J7.4, J7.5, J7.6, J7.7, J7.8, J7.9, J7.10, J7.11, J7.12, J7.24, J7.P1, J7.P2, J7.P3, J7.P4, Q1.2, Q2.2, R18.1, R19.1, R20.1, U5.4 (GND), U5.9 (EPAD), U6.C2 (VSS), U6.E4 (VSS), U6.E5 (VSS), U6.E6 (VSS), U6.G1 (VSSA), U6.J1 (VSS), U7.D1 (GND), U16.D1 (GND); also elsewhere on the board
HP_DET: U7.E3 (A8); also elsewhere on the board
HP_DET_MCU: U6.J10 (PD13), U7.E2 (B8)
LED_DATA: U6.K2 (PA3); also elsewhere on the board
MCP_PG: U6.G10 (PB15); also elsewhere on the board
MCP_STAT1: R24.1, U6.H10 (PB14); also elsewhere on the board
MCP_STAT2: R23.1, U6.H9 (PD10); also elsewhere on the board
MCU_AUD_BCLK_H: U6.H3 (PA5), U7.B2 (B3)
MCU_AUD_BCLK_L: U7.B3 (A3); also elsewhere on the board
MCU_AUD_OUT_L: U7.B4 (A4); also elsewhere on the board
MCU_AUD_OUT_L_H: U6.K3 (PA7), U7.B1 (B4)
MCU_AUD_SYNC_H: U6.G3 (PA4), U7.C2 (B5)
MCU_AUD_SYNC_L: U7.C3 (A5); also elsewhere on the board
MCU_CTS: U6.C10 (PA11), U16.D2 (B7)
MCU_DCD: U6.C7 (PD3), U16.A2 (B1)
MCU_DSR: U6.D9 (PA8), U16.B1 (B4)
MCU_DTR: U6.D8 (PD0), U16.A1 (B2)
MCU_RI: U6.F10 (PC6), U16.E2 (B8)
MCU_RTS: U6.B10 (PA12), U16.C2 (B5)
MCU_RXD: U6.D10 (PA10), U16.E1 (B6)
MCU_TXD: U6.C9 (PA9), U16.B2 (B3)
MOB_AUD_BCLK: J9.9; also elsewhere on the board
MOB_AUD_IN: J9.10; also elsewhere on the board
MOB_AUD_OUT: J9.11; also elsewhere on the board
MOB_AUD_SYNC: J9.12; also elsewhere on the board
MOB_CTS: J9.18, U16.D3 (A7); also elsewhere on the board
MOB_DCD: J9.13, U16.A3 (A1); also elsewhere on the board
MOB_DSR: J9.15, U16.B4 (A4); also elsewhere on the board
MOB_DTR: J9.14, U16.A4 (A2); also elsewhere on the board
MOB_PWR: J9.1, Q1.3; also elsewhere on the board
MOB_PWR_CTL: R16.2, U6.A2 (PC13)
MOB_RI: J9.20, U16.E3 (A8); also elsewhere on the board
MOB_RST: J9.2, Q2.3; also elsewhere on the board
MOB_RST_CTL: R17.2, U6.A1 (PC14)
MOB_RTS: J9.17, U16.C3 (A5); also elsewhere on the board
MOB_RXD: J9.19, U16.E4 (A6); also elsewhere on the board
MOB_SAFE_PWR_REMOVE_H: U6.J9 (PD9), U7.A1 (B2)
MOB_SAFE_PWR_REMOVE_L: J9.3, U7.A4 (A2); also elsewhere on the board
MOB_TXD: J9.16, U16.B3 (A3); also elsewhere on the board
MOB_WAKE_H: U6.K9 (PD8), U7.D2 (B7)
MOB_WAKE_L: J9.4, U7.D3 (A7); also elsewhere on the board
unnamed: C25.1, U6.E7 (VCAP)
unnamed: C26.1, U6.F8 (VCAP)
unnamed: Q1.1, R16.1, R18.2
unnamed: Q2.1, R17.1, R19.2
unnamed: R20.2, U6.D5 (BOOT0)
PB_0: U6.A3 (PE2); also elsewhere on the board
PB_1: U6.C3 (PE4); also elsewhere on the board
PB_2: U6.A5 (PB7); also elsewhere on the board
PB_3: U6.A6 (PB4(NJTRST)); also elsewhere on the board
PB_4: U6.C1 (PH0); also elsewhere on the board
PB_5: U6.C5 (PB5); also elsewhere on the board
PB_6: U6.B6 (PD5); also elsewhere on the board
PB_7: U6.D3 (PE5); also elsewhere on the board
PB_8: U6.C4 (PE1); also elsewhere on the board
PB_9: U6.B5 (PB6); also elsewhere on the board
PB_CALL: U6.B1 (PC15); also elsewhere on the board
PB_DPAD_DOWN: U6.B3 (PE3); also elsewhere on the board
PB_DPAD_LEFT: U6.G4 (PC4); also elsewhere on the board
PB_DPAD_RIGHT: U6.C6 (PD6); also elsewhere on the board
PB_DPAD_SELECT: U6.F1 (PC0); also elsewhere on the board
PB_DPAD_UP: U6.F2 (PC1); also elsewhere on the board
PB_END_CALL: U6.D6 (PD7); also elsewhere on the board
PB_HASH: U6.D4 (PE0); also elsewhere on the board
PB_MENU_L: U6.G2 (PA0); also elsewhere on the board
PB_MENU_R: U6.D7 (PD4); also elsewhere on the board
PB_PWR: U6.K8 (PB12); also elsewhere on the board
PB_STAR: U6.E3 (PE6); also elsewhere on the board
PB_VOL_DOWN: U6.H2 (PA1); also elsewhere on the board
PB_VOL_UP: U6.J2 (PA2); also elsewhere on the board
RST: C20.2, J6.3 (~RESET), U6.E1 (NRST)
SCL: R22.1, U5.7 (SCLB), U6.B4 (PB8); also elsewhere on the board
SDA: R4.1, U5.6 (SDAB), U6.A4 (PB9); also elsewhere on the board
SIM_CLK: J9.22; also elsewhere on the board
SIM_DATA: J9.23; also elsewhere on the board
SIM_RST: J9.21; also elsewhere on the board
SIM_VDD: J9.24; also elsewhere on the board
SWCLK: J6.4 (SWCLK), U6.A9 (PA14(JTCK)
SWDIO: J6.2 (SWDIO), U6.A10 (PA13(JTMS)
SWO: J6.6 (SWO), U6.A7 (PB3(JTDO)
VBAT: J7.13, J7.14, J7.15, J7.16, J7.17, J7.18, J7.19; also elsewhere on the board
VIB_EN: U6.K5 (PE9); also elsewhere on the board
VIB_PWM: U6.K4 (PB1); also elsewhere on the board
uSD_CLK: U6.C8 (PC12); also elsewhere on the board
uSD_CMD: U6.B7 (PD2); also elsewhere on the board
uSD_DAT0: U6.F9 (PC8); also elsewhere on the board
uSD_DAT1: U6.E9 (PC9); also elsewhere on the board
uSD_DAT2: U6.B9 (PC10); also elsewhere on the board
uSD_DAT3: U6.B8 (PC11); also elsewhere on the board
uSD_DET: U6.E10 (PC7); also elsewhere on the board

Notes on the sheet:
Max data rate = 60Mbps
MOVED PB3 CHECK IOC
Programmer
MCU
Mezzanine Connectors
CHECK PINOUT
Logic Level Shifting
ENSURE VREF

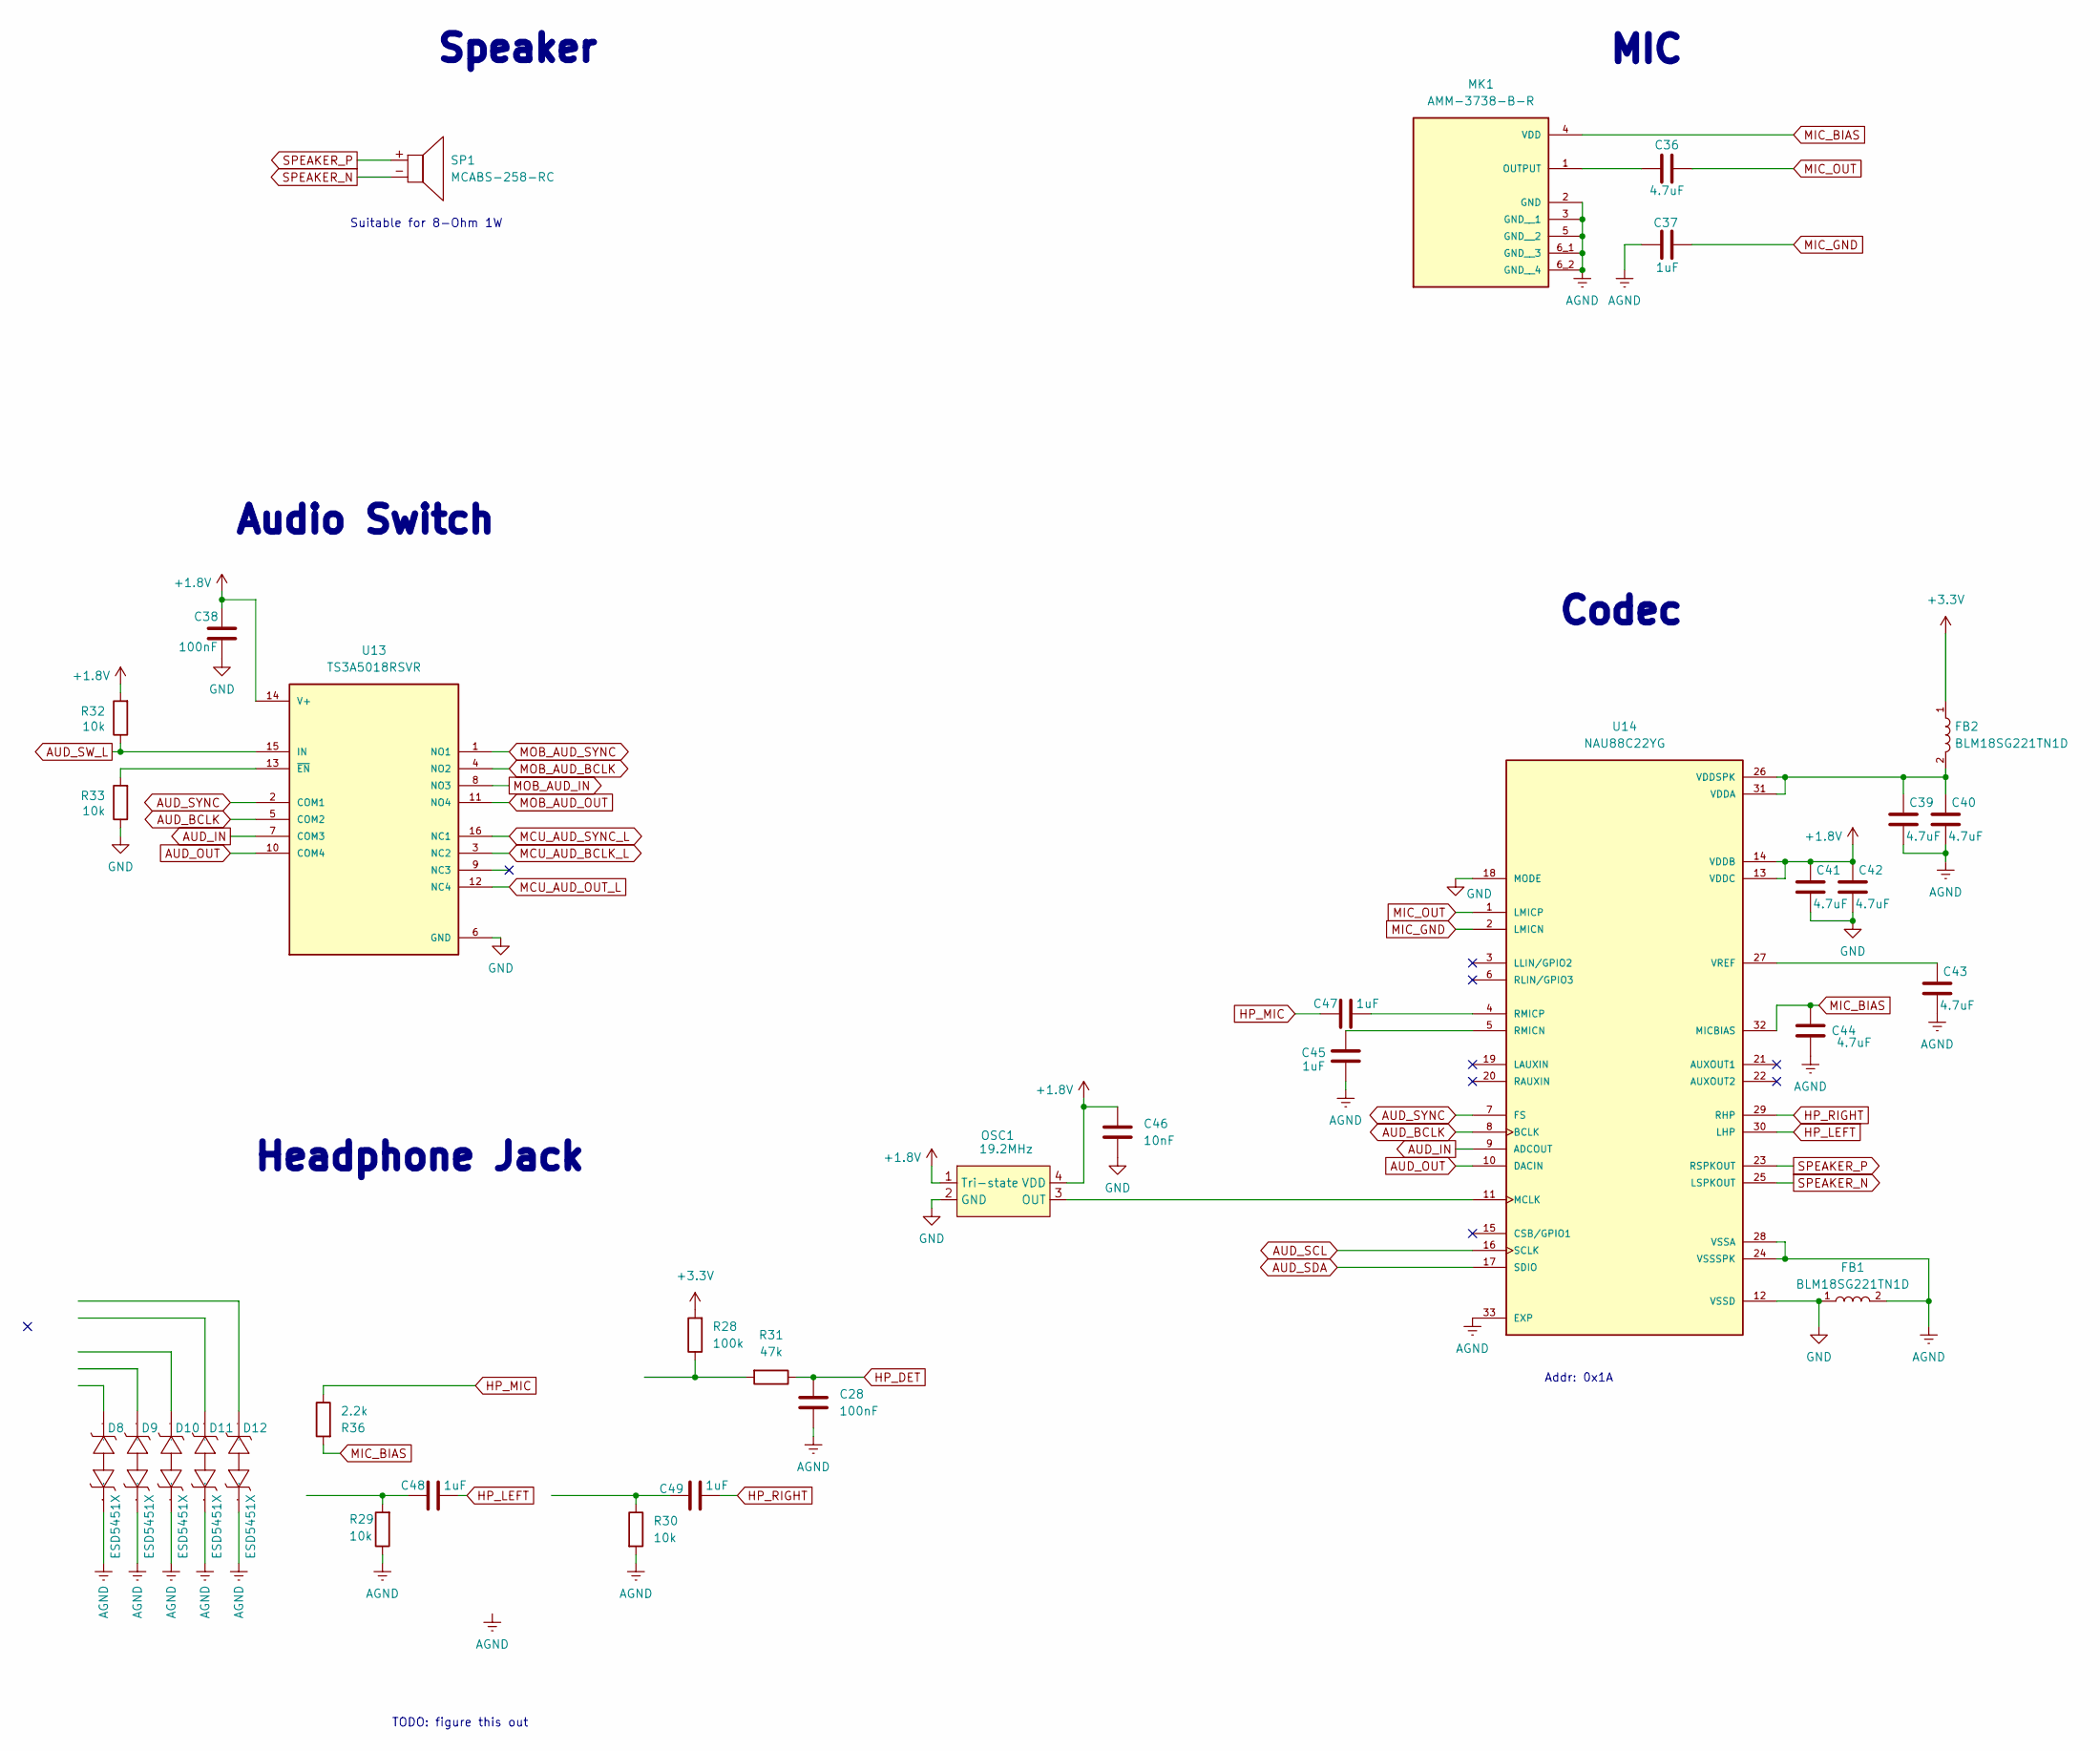
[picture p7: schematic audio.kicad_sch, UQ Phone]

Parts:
C28, C38: 100nF; C_0201_0603Metric; LCSC PN C160831
C36, C39, C40, C41, C42, C43, C44: 4.7uF; C_0201_0603Metric; LCSC PN C335103
C37, C45, C47, C48, C49: 1uF; C_0201_0603Metric; LCSC PN C53067
C46: 10nF; C_0402_1005Metric; LCSC PN C15195
D8, D9, D10, D11, D12: ESD5451X; WBFBP-02C_L1.0-W0.6-BI; Manufacturer Part ESD5451X-2/TR; LCSC Part Name ESD5451X-2/TR
FB1, FB2: BLM18SG221TN1D; BEADC1608X65N; DigiKey_Part_Number 490-5225-2-ND
MK1: AMM-3738-B-R; MIC_AMM-3738-B-R; PARTREV A; DigiKey_Part_Number 668-AMM-3738-B-RTR-ND
OSC1: 19.2MHz; OSC-SMD_4P-L2.0-W1.6-BL; Manufacturer Part OT7EL89CJI-111YLC-19.2M; LCSC Part Name YSO110TR 19.2MHZ 4P 2016 1.8V-3.3V ±10P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
R28: 100k; R_0201_0603Metric; LCSC PN C106224
R29, R30, R32, R33: 10k; R_0201_0603Metric; LCSC PN C106225
R31: 47k; R_0201_0603Metric; LCSC PN C138139
R36: 2.2k; R_0201_0603Metric; LCSC PN C142018
SP1: MCABS-258-RC
U13: TS3A5018RSVR; QFN40P260X180X55-16N; PARTREV 4220314/C 02/2020; DigiKey_Part_Number 296-27552-2-ND
U14: NAU88C22YG; QFN50P500X500X80-33N; PARTREV 3.3; DigiKey_Part_Number NAU88C22YG-ND

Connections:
+1.8V: C38.1, C41.1, C42.1, C46.1, OSC1.1 (Tri-state), OSC1.4 (VDD), R32.2, U13.14 (V+), U14.13 (VDDC), U14.14 (VDDB); also elsewhere on the board
+3.3V: FB2.1, R28.2; also elsewhere on the board
AGND: C28.2, C37.1, C39.2, C40.2, C43.2, C44.2, C45.2, D8.1, D9.1, D10.1, D11.1, D12.1, FB1.2, MK1.2 (GND), MK1.3 (GND__1), MK1.5 (GND__2), MK1.6_1 (GND__3), MK1.6_2 (GND__4), R29.1, R30.2, U14.24 (VSSSPK), U14.28 (VSSA), U14.33 (EXP); also elsewhere on the board
AUD_BCLK: U13.5 (COM2), U14.8 (BCLK)
AUD_IN: U13.7 (COM3), U14.9 (ADCOUT)
AUD_OUT: U13.10 (COM4), U14.10 (DACIN)
AUD_SCL: U14.16 (SCLK); also elsewhere on the board
AUD_SDA: U14.17 (SDIO); also elsewhere on the board
AUD_SW_L: R32.1, U13.15 (IN); also elsewhere on the board
AUD_SYNC: U13.2 (COM1), U14.7 (FS)
GND: C38.2, C41.2, C42.2, C46.2, FB1.1, OSC1.2 (GND), R33.1, U13.6 (GND), U14.12 (VSSD), U14.18 (MODE); also elsewhere on the board
HP_DET: C28.1, R31.1; also elsewhere on the board
HP_LEFT: C48.1, U14.30 (LHP)
HP_MIC: C47.2, R36.1
HP_RIGHT: C49.1, U14.29 (RHP)
MCU_AUD_BCLK_L: U13.3 (NC2); also elsewhere on the board
MCU_AUD_OUT_L: U13.12 (NC4); also elsewhere on the board
MCU_AUD_SYNC_L: U13.16 (NC1); also elsewhere on the board
MIC_BIAS: C44.1, MK1.4 (VDD), R36.2, U14.32 (MICBIAS)
MIC_GND: C37.2, U14.2 (LMICN)
MIC_OUT: C36.2, U14.1 (LMICP)
MOB_AUD_BCLK: U13.4 (NO2); also elsewhere on the board
MOB_AUD_IN: U13.8 (NO3); also elsewhere on the board
MOB_AUD_OUT: U13.11 (NO4); also elsewhere on the board
MOB_AUD_SYNC: U13.1 (NO1); also elsewhere on the board
unnamed: C48.2, R29.2
unnamed: C49.2, R30.1
unnamed: C36.1, MK1.1 (OUTPUT)
unnamed: OSC1.3 (OUT), U14.11 (MCLK)
unnamed: R28.1, R31.2
unnamed: R33.2, U13.13 (~EN)
unnamed: C45.1, U14.5 (RMICN)
unnamed: C47.1, U14.4 (RMICP)
unnamed: C39.1, C40.1, FB2.2, U14.26 (VDDSPK), U14.31 (VDDA)
unnamed: C43.1, U14.27 (VREF)
SPEAKER_N: SP1.-, U14.25 (LSPKOUT)
SPEAKER_P: SP1.+, U14.23 (RSPKOUT)

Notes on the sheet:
Suitable for 8-Ohm 1W
Addr: 0x1A
TODO: figure this out
Codec
Headphone Jack
Speaker
MIC
Audio Switch

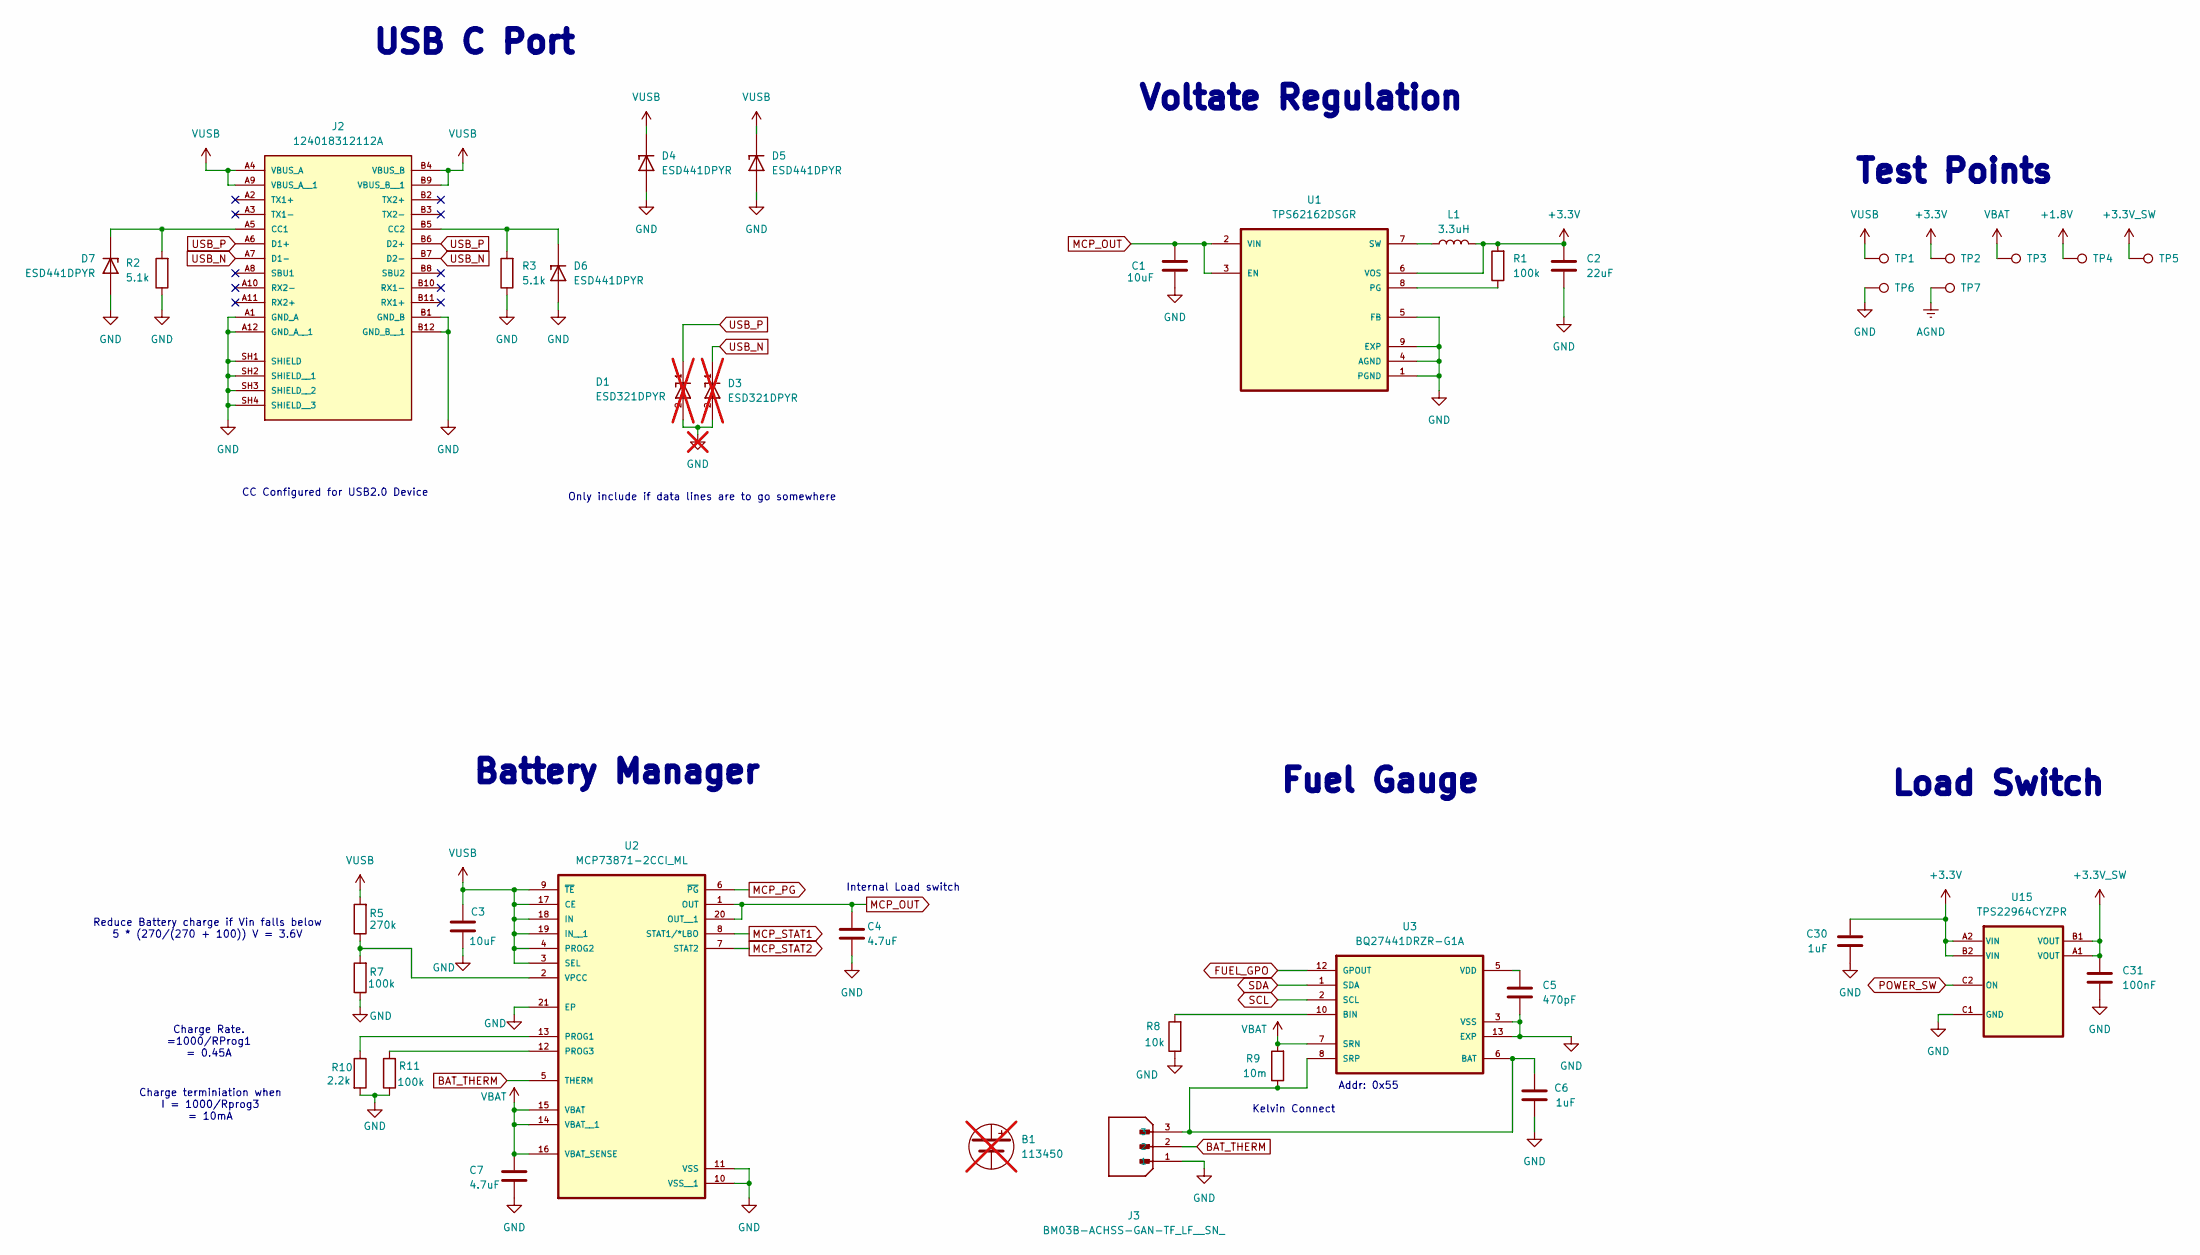
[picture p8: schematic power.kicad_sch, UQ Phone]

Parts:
B1: 113450; not fitted
C1, C3: 10uF; C_0603_1608Metric; LCSC PN C2168196
C2: 22uF; C_0603_1608Metric; LCSC PN C3020456
C4, C7: 4.7uF; C_0201_0603Metric; LCSC PN C335103
C5: 470pF; C_0402_1005Metric; LCSC PN C26412
C6, C30: 1uF; C_0201_0603Metric; LCSC PN C53067
C31: 100nF; C_0201_0603Metric; LCSC PN C160831
D1, D3: ESD321DPYR; TVS_ESD321DPYR; PARTREV B; DigiKey_Part_Number 296-51108-2-ND; not fitted
D4, D5, D6, D7: ESD441DPYR; DIODFN60X30X32-2N; PARTREV B; LCSC PN C22427765
J2: 124018312112A; AMPHENOL_124018312112A; PARTREV 1; DigiKey_Part_Number 124018312112ATR-ND
J3: BM03B-ACHSS-GAN-TF_LF__SN_; JST_BM03B-ACHSS-GAN-TF_LF__SN_; PARTREV N/A
L1: 3.3uH; INDC2520X120N; DigiKey_Part_Number 587-3227-2-ND
R1, R7, R11: 100k; R_0201_0603Metric; LCSC PN C106224
R2, R3: 5.1k; R_0201_0603Metric; LCSC PN C274341
R5: 270k; R_0201_0603Metric; LCSC PN C851694
R8: 10k; R_0201_0603Metric; LCSC PN C106225
R9: 10m; R_0805_2012Metric; LCSC PN C723359
R10: 2.2k; R_0201_0603Metric; LCSC PN C142018
TP1, TP2, TP3, TP4, TP5, TP6, TP7: TestPoint; TestPoint_Pad_D1.5mm
U1: TPS62162DSGR; SON50P200X200X80-9N; PARTREV E; DigiKey_Part_Number 296-43671-2-ND
U2: MCP73871-2CCI_ML; QFN50P400X400X100-21N; LCSC PN C5121473
U3: BQ27441DRZR-G1A; IC_BQ27441DRZR-G1A; LCSC PN C473397
U15: TPS22964CYZPR; IC_SN74LVC2G34YZPR; LCSC PN C431579

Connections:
+1.8V: TP4.1; also elsewhere on the board
+3.3V: C2.1, C30.1, L1.2, R1.2, TP2.1, U1.6 (VOS), U15.A2 (VIN), U15.B2 (VIN); also elsewhere on the board
+3.3V_SW: C31.1, TP5.1, U15.A1 (VOUT), U15.B1 (VOUT); also elsewhere on the board
AGND: TP7.1; also elsewhere on the board
BAT_THERM: J3.2, U2.5 (THERM)
FUEL_GPO: U3.12 (GPOUT); also elsewhere on the board
GND: C1.1, C2.2, C3.2, C4.2, C5.2, C6.2, C7.2, C30.2, C31.2, D1.2, D3.2, D4.2, D5.2, D6.2, D7.2, J2.A1 (GND_A), J2.A12 (GND_A__1), J2.B1 (GND_B), J2.B12 (GND_B__1), J2.SH1 (SHIELD), J2.SH2 (SHIELD__1), J2.SH3 (SHIELD__2), J2.SH4 (SHIELD__3), J3.1, R2.1, R3.1, R7.1, R8.1, R10.2, R11.1, TP6.1, U1.1 (PGND), U1.4 (AGND), U1.5 (FB), U1.9 (EXP), U2.10 (VSS__1), U2.11 (VSS), U2.21 (EP), U3.3 (VSS), U3.13 (EXP), U15.C1 (GND); also elsewhere on the board
MCP_OUT: C1.2, C4.1, U1.2 (VIN), U1.3 (EN), U2.1 (OUT), U2.20 (OUT__1)
MCP_PG: U2.6 (~PG); also elsewhere on the board
MCP_STAT1: U2.8 (STAT1/*LBO); also elsewhere on the board
MCP_STAT2: U2.7 (STAT2); also elsewhere on the board
unnamed: D7.1, J2.A5 (CC1), R2.2
unnamed: D6.1, J2.B5 (CC2), R3.2
unnamed: R1.1, U1.8 (PG)
unnamed: L1.1, U1.7 (SW)
unnamed: R10.1, U2.13 (PROG1)
unnamed: R11.2, U2.12 (PROG3)
unnamed: R5.1, R7.2, U2.2 (VPCC)
unnamed: C6.1, J3.3, R9.1, U3.6 (BAT), U3.8 (SRP)
unnamed: R8.2, U3.10 (BIN)
unnamed: C5.1, U3.5 (VDD)
POWER_SW: U15.C2 (ON)
SCL: U3.2 (SCL); also elsewhere on the board
SDA: U3.1 (SDA); also elsewhere on the board
USB_N: D3.1, J2.A7 (D1-), J2.B7 (D2-)
USB_P: D1.1, J2.A6 (D1+), J2.B6 (D2+)
VBAT: C7.1, R9.2, TP3.1, U2.14 (VBAT__1), U2.15 (VBAT), U2.16 (VBAT_SENSE), U3.7 (SRN); also elsewhere on the board
VUSB: C3.1, D4.1, D5.1, J2.A4 (VBUS_A), J2.A9 (VBUS_A__1), J2.B4 (VBUS_B), J2.B9 (VBUS_B__1), R5.2, TP1.1, U2.3 (SEL), U2.4 (PROG2), U2.9 (~TE), U2.17 (CE), U2.18 (IN), U2.19 (IN__1)

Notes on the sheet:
Battery Manager
CC Configured for USB2.0 Device
Charge Rate. =1000/RProg1 = 0.45A
Load Switch
Addr: 0x55
Voltate Regulation
Kelvin Connect
Reduce Battery charge if Vin falls below 5 * (270/(270 + 100)) V = 3.6V
Internal Load switch
Only include if data lines are to go somewhere
Charge terminiation when I = 1000/Rprog3 = 10mA
Fuel Gauge
USB C Port
Test Points

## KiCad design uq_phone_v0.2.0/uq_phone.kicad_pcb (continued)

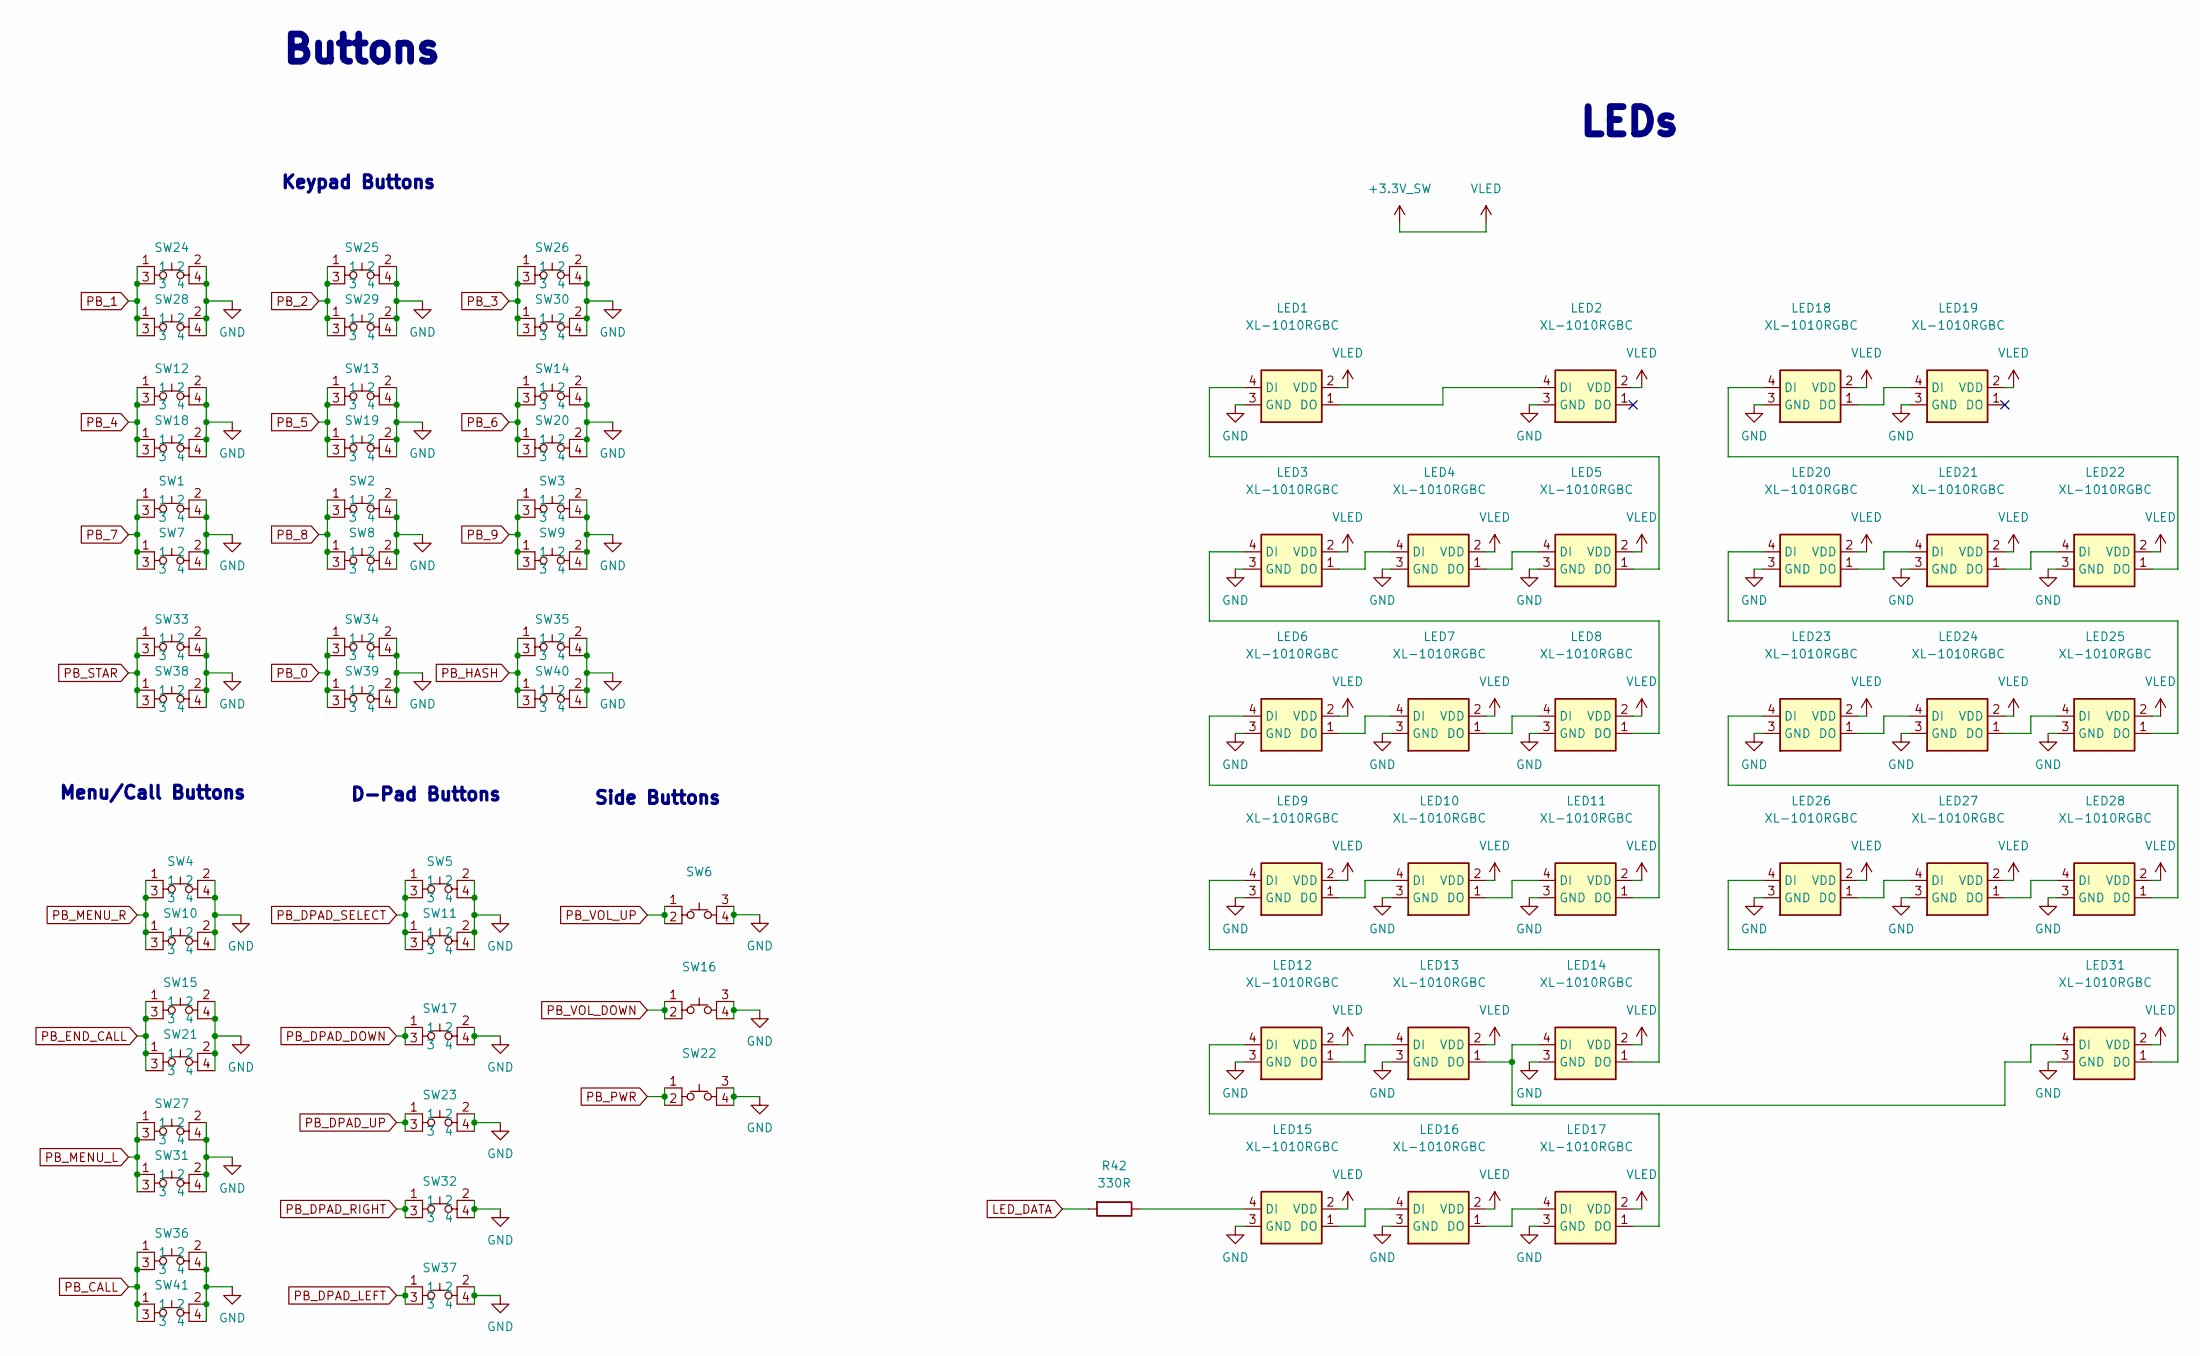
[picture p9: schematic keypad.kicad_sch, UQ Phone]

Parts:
LED1, LED2, LED3, LED4, LED5, LED6, LED7, LED8, LED9, LED10, LED11, LED12, LED13, LED14, LED15, LED16, LED17, LED18, LED20, LED21, LED22, LED23, LED24, LED25, LED26, LED27, LED28, LED31: XL-1010RGBC; XL-1010RGBC-WS2812B; LCSC PN C5349953
LED19: XL-1010RGBC; XL-1010RGBC-Alt; LCSC PN C5349953
R42: 330R; R_0402_1005Metric; LCSC PN C6117577
SW1, SW2, SW3, SW4, SW5, SW7, SW8, SW9, SW10, SW11, SW12, SW13, SW14, SW15, SW17, SW18, SW19, SW20, SW21, SW23, SW24, SW25, SW26, SW27, SW28, SW29, SW30, SW31, SW32, SW33, SW34, SW35, SW36, SW37, SW38, SW39, SW40, SW41: SKTAAAE010; LCSC PN C358616
SW6, SW16, SW22: SKSCLCE010; LCSC PN C139799

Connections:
+3.3V_SW: LED1.2 (VDD), LED2.2 (VDD), LED3.2 (VDD), LED4.2 (VDD), LED5.2 (VDD), LED6.2 (VDD), LED7.2 (VDD), LED8.2 (VDD), LED9.2 (VDD), LED10.2 (VDD), LED11.2 (VDD), LED12.2 (VDD), LED13.2 (VDD), LED14.2 (VDD), LED15.2 (VDD), LED16.2 (VDD), LED17.2 (VDD), LED18.2 (VDD), LED19.2 (VDD), LED20.2 (VDD), LED21.2 (VDD), LED22.2 (VDD), LED23.2 (VDD), LED24.2 (VDD), LED25.2 (VDD), LED26.2 (VDD), LED27.2 (VDD), LED28.2 (VDD), LED31.2 (VDD); also elsewhere on the board
GND: LED1.3 (GND), LED2.3 (GND), LED3.3 (GND), LED4.3 (GND), LED5.3 (GND), LED6.3 (GND), LED7.3 (GND), LED8.3 (GND), LED9.3 (GND), LED10.3 (GND), LED11.3 (GND), LED12.3 (GND), LED13.3 (GND), LED14.3 (GND), LED15.3 (GND), LED16.3 (GND), LED17.3 (GND), LED18.3 (GND), LED19.3 (GND), LED20.3 (GND), LED21.3 (GND), LED22.3 (GND), LED23.3 (GND), LED24.3 (GND), LED25.3 (GND), LED26.3 (GND), LED27.3 (GND), LED28.3 (GND), LED31.3 (GND), SW1.2, SW1.4, SW2.2, SW2.4, SW3.2, SW3.4, SW4.2, SW4.4, SW5.2, SW5.4, SW6.3, SW6.4, SW7.2, SW7.4, SW8.2, SW8.4, SW9.2, SW9.4, SW10.2, SW10.4, SW11.2, SW11.4, SW12.2, SW12.4, SW13.2, SW13.4, SW14.2, SW14.4, SW15.2, SW15.4, SW16.3, SW16.4, SW17.2, SW17.4, SW18.2, SW18.4, SW19.2, SW19.4, SW20.2, SW20.4, SW21.2, SW21.4, SW22.3, SW22.4, SW23.2, SW23.4, SW24.2, SW24.4, SW25.2, SW25.4, SW26.2, SW26.4, SW27.2, SW27.4, SW28.2, SW28.4, SW29.2, SW29.4, SW30.2, SW30.4, SW31.2, SW31.4, SW32.2, SW32.4, SW33.2, SW33.4, SW34.2, SW34.4, SW35.2, SW35.4, SW36.2, SW36.4, SW37.2, SW37.4, SW38.2, SW38.4, SW39.2, SW39.4, SW40.2, SW40.4, SW41.2, SW41.4; also elsewhere on the board
LED_DATA: R42.2; also elsewhere on the board
unnamed: LED1.4 (DI), LED5.1 (DO)
unnamed: LED1.1 (DO), LED2.4 (DI)
unnamed: LED3.4 (DI), LED8.1 (DO)
unnamed: LED3.1 (DO), LED4.4 (DI)
unnamed: LED4.1 (DO), LED5.4 (DI)
unnamed: LED6.1 (DO), LED7.4 (DI)
unnamed: LED7.1 (DO), LED8.4 (DI)
unnamed: LED9.1 (DO), LED10.4 (DI)
unnamed: LED10.1 (DO), LED11.4 (DI)
unnamed: LED6.4 (DI), LED11.1 (DO)
unnamed: LED12.4 (DI), LED17.1 (DO)
unnamed: LED12.1 (DO), LED13.4 (DI)
unnamed: LED13.1 (DO), LED14.4 (DI), LED31.4 (DI)
unnamed: LED9.4 (DI), LED14.1 (DO)
unnamed: LED15.4 (DI), R42.1
unnamed: LED15.1 (DO), LED16.4 (DI)
unnamed: LED16.1 (DO), LED17.4 (DI)
unnamed: LED18.4 (DI), LED22.1 (DO)
unnamed: LED18.1 (DO), LED19.4 (DI)
unnamed: LED20.4 (DI), LED25.1 (DO)
unnamed: LED20.1 (DO), LED21.4 (DI)
unnamed: LED21.1 (DO), LED22.4 (DI)
unnamed: LED23.4 (DI), LED28.1 (DO)
unnamed: LED23.1 (DO), LED24.4 (DI)
unnamed: LED24.1 (DO), LED25.4 (DI)
unnamed: LED26.4 (DI), LED31.1 (DO)
unnamed: LED26.1 (DO), LED27.4 (DI)
unnamed: LED27.1 (DO), LED28.4 (DI)
PB_0: SW34.1, SW34.3, SW39.1, SW39.3; also elsewhere on the board
PB_1: SW24.1, SW24.3, SW28.1, SW28.3; also elsewhere on the board
PB_2: SW25.1, SW25.3, SW29.1, SW29.3; also elsewhere on the board
PB_3: SW26.1, SW26.3, SW30.1, SW30.3; also elsewhere on the board
PB_4: SW12.1, SW12.3, SW18.1, SW18.3; also elsewhere on the board
PB_5: SW13.1, SW13.3, SW19.1, SW19.3; also elsewhere on the board
PB_6: SW14.1, SW14.3, SW20.1, SW20.3; also elsewhere on the board
PB_7: SW1.1, SW1.3, SW7.1, SW7.3; also elsewhere on the board
PB_8: SW2.1, SW2.3, SW8.1, SW8.3; also elsewhere on the board
PB_9: SW3.1, SW3.3, SW9.1, SW9.3; also elsewhere on the board
PB_CALL: SW36.1, SW36.3, SW41.1, SW41.3; also elsewhere on the board
PB_DPAD_DOWN: SW17.1, SW17.3; also elsewhere on the board
PB_DPAD_LEFT: SW37.1, SW37.3; also elsewhere on the board
PB_DPAD_RIGHT: SW32.1, SW32.3; also elsewhere on the board
PB_DPAD_SELECT: SW5.1, SW5.3, SW11.1, SW11.3; also elsewhere on the board
PB_DPAD_UP: SW23.1, SW23.3; also elsewhere on the board
PB_END_CALL: SW15.1, SW15.3, SW21.1, SW21.3; also elsewhere on the board
PB_HASH: SW35.1, SW35.3, SW40.1, SW40.3; also elsewhere on the board
PB_MENU_L: SW27.1, SW27.3, SW31.1, SW31.3; also elsewhere on the board
PB_MENU_R: SW4.1, SW4.3, SW10.1, SW10.3; also elsewhere on the board
PB_PWR: SW22.1, SW22.2; also elsewhere on the board
PB_STAR: SW33.1, SW33.3, SW38.1, SW38.3; also elsewhere on the board
PB_VOL_DOWN: SW16.1, SW16.2; also elsewhere on the board
PB_VOL_UP: SW6.1, SW6.2; also elsewhere on the board

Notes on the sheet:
Side Buttons
LEDs
D-Pad Buttons
Keypad Buttons
Menu/Call Buttons
Buttons

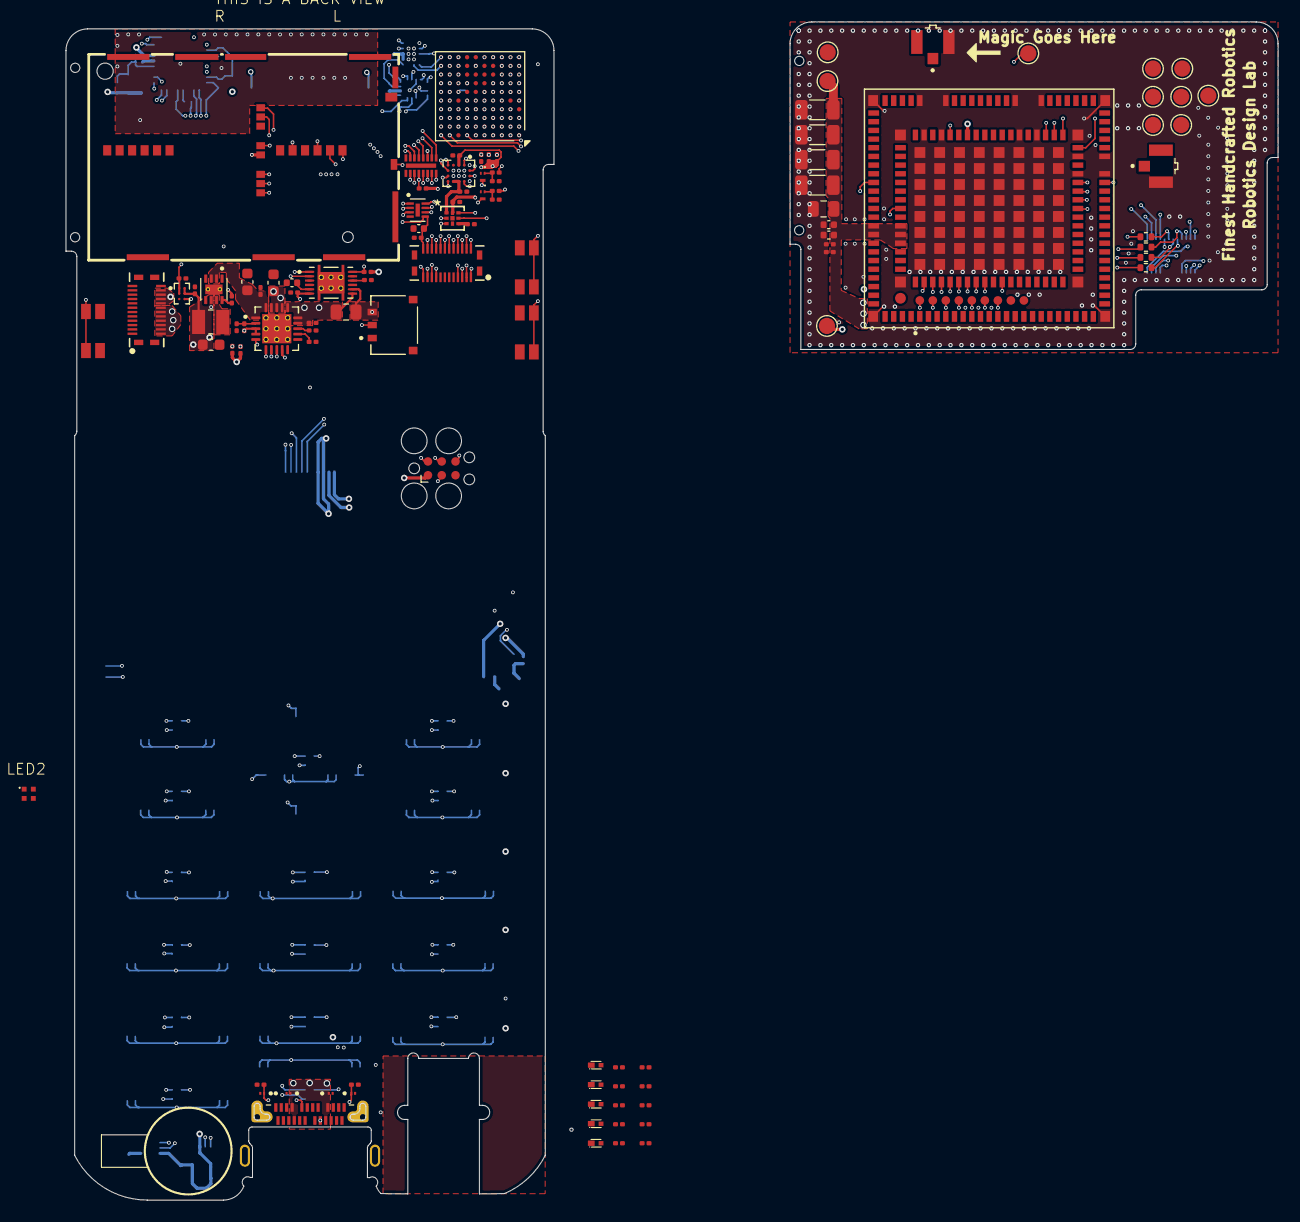
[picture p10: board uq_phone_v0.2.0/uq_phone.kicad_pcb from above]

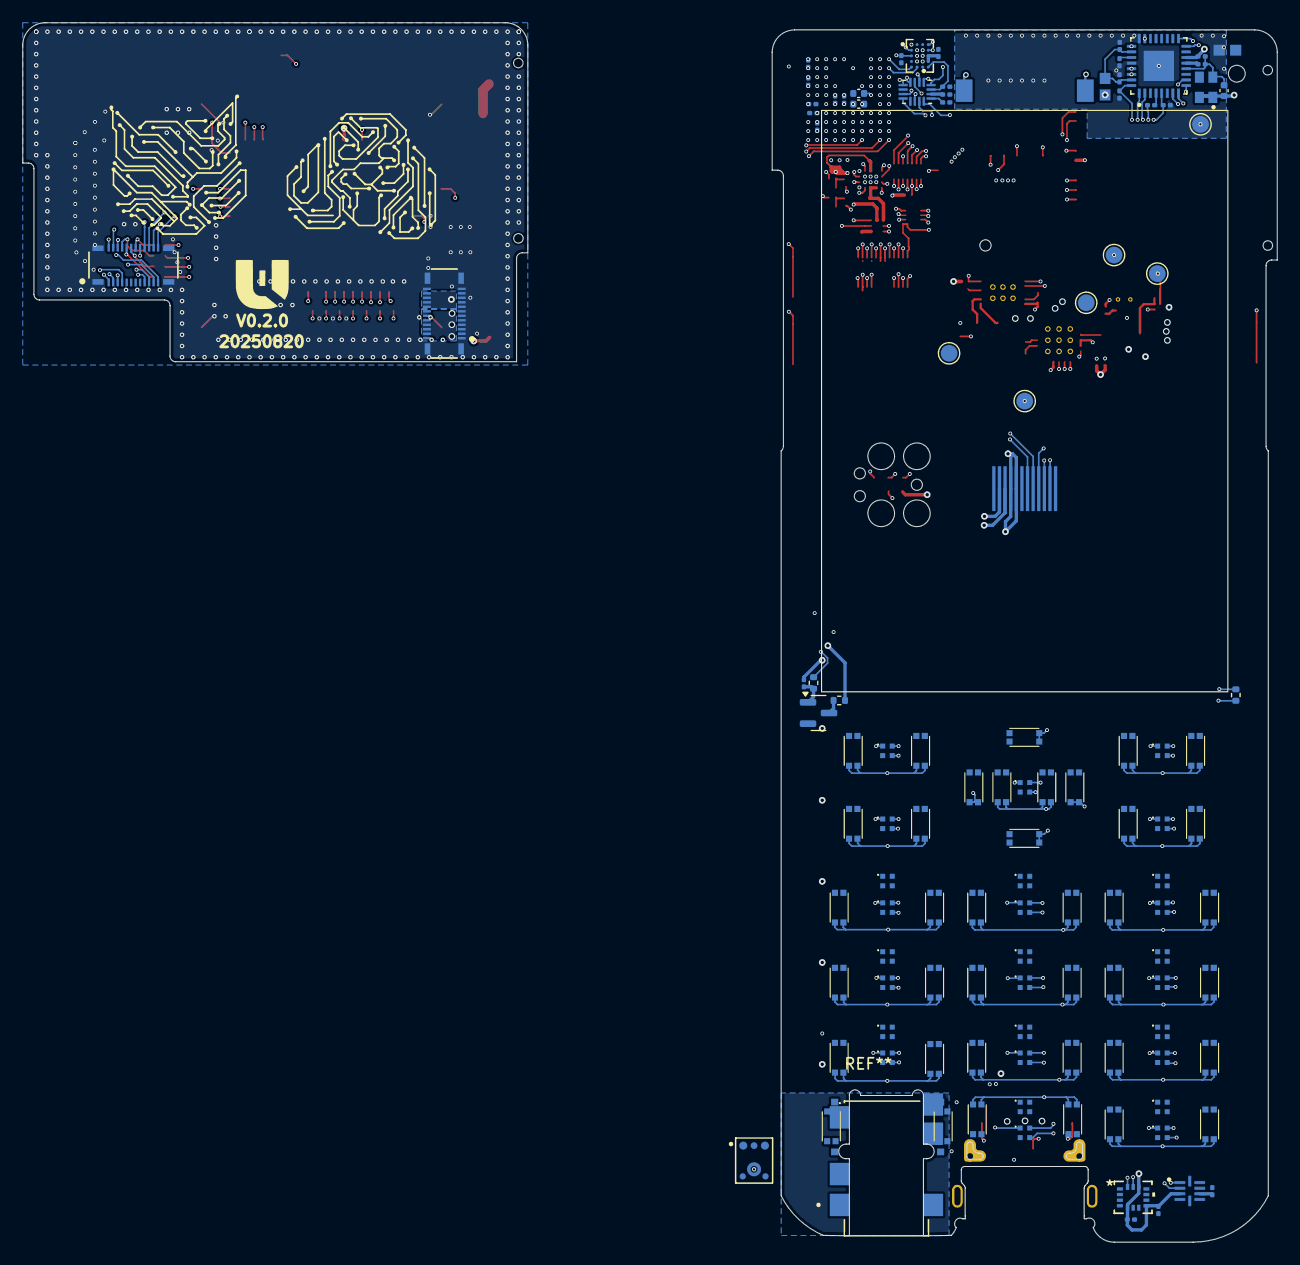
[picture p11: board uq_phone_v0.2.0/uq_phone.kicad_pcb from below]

Board: 6 copper layers, 111.8 x 108.6 mm, 220 parts (116 on the bottom side), 198 nets.

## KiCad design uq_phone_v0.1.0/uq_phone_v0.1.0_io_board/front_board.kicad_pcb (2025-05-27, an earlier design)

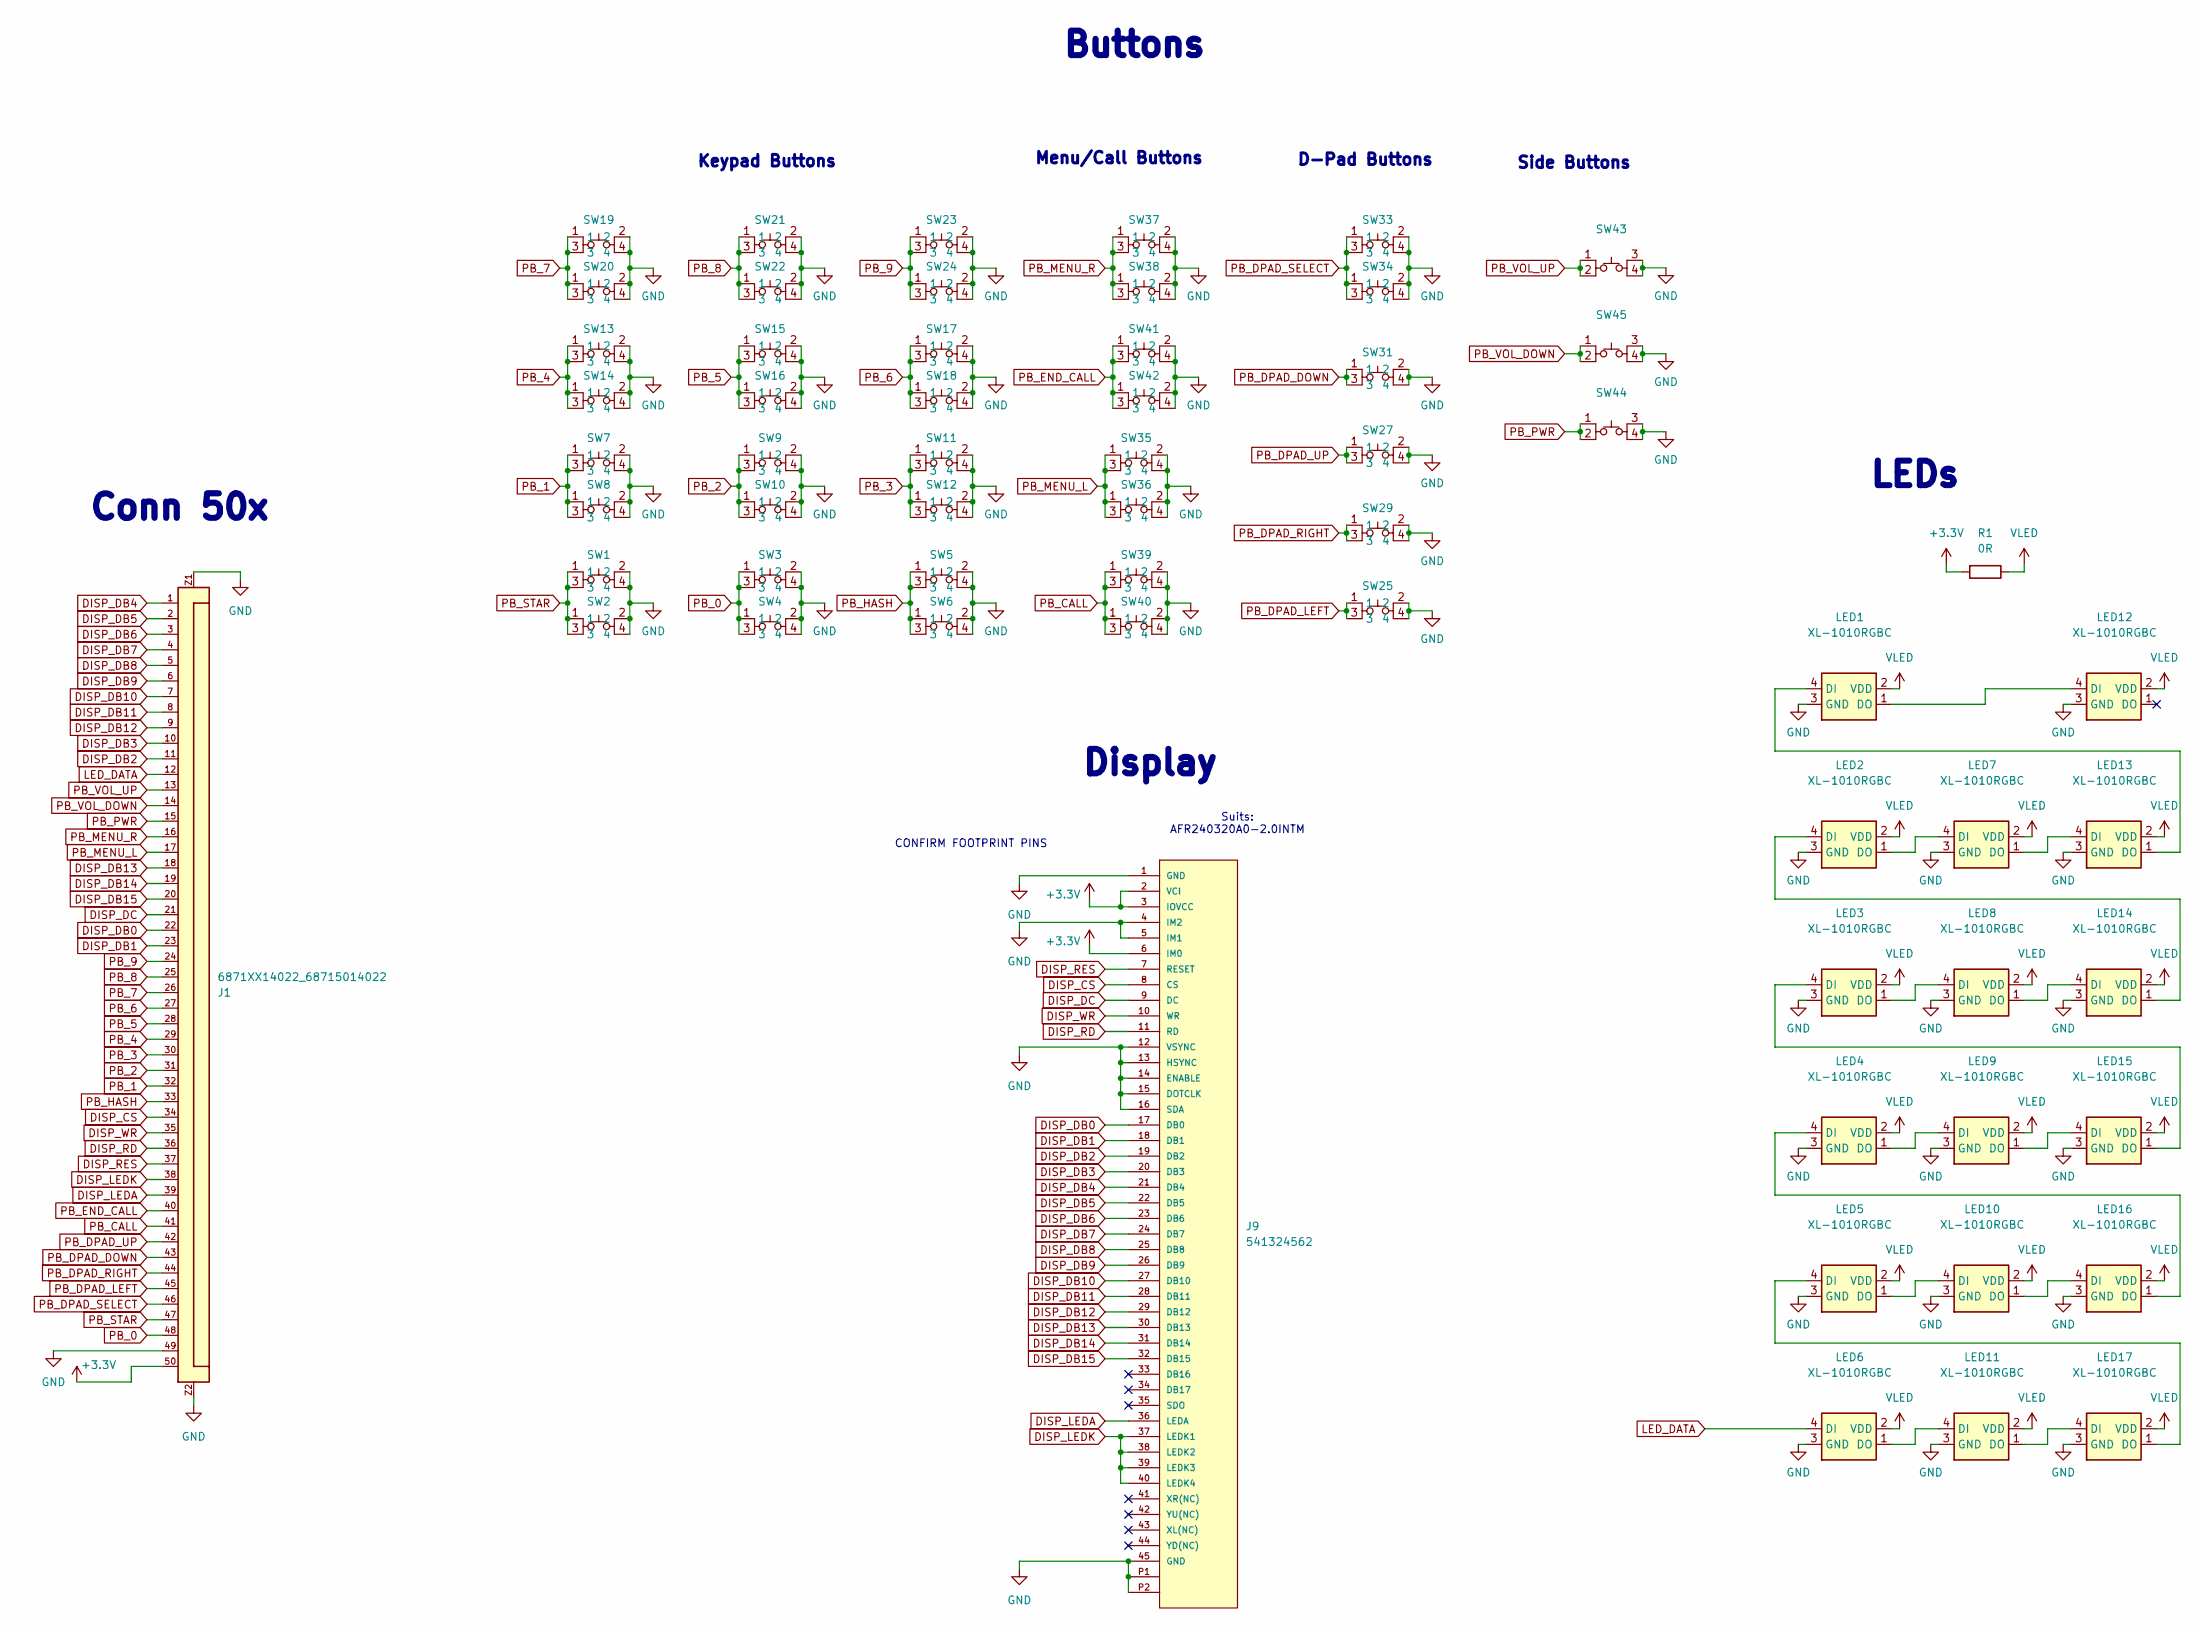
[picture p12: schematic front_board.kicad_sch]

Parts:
J1: 6871XX14022_68715014022; 68715014022
J9: 541324562; CON_541324562_MOL; MANUFACTURER_PART_NUMBER 541324562; DigiKey_Part_Number WM8850TR-ND
LED1, LED2, LED3, LED4, LED5, LED6, LED7, LED8, LED9, LED10, LED11, LED12, LED13, LED14, LED15, LED16, LED17: XL-1010RGBC; XL-1010RGBC-WS2812B; LCSC PN C5349953
R1: 0R; R_0603_1608Metric; LCSC PN C95177
SW1, SW2, SW3, SW4, SW5, SW6, SW7, SW8, SW9, SW10, SW11, SW12, SW13, SW14, SW15, SW16, SW17, SW18, SW19, SW20, SW21, SW22, SW23, SW24, SW25, SW27, SW29, SW31, SW33, SW34, SW35, SW36, SW37, SW38, SW39, SW40, SW41, SW42: SKTAAAE010; LCSC PN C358616
SW43, SW44, SW45: SKSCLCE010; LCSC PN C139799

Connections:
+3.3V: J1.50, J9.2 (VCI), J9.3 (IOVCC), J9.6 (IM0), R1.2
DISP_CS: J1.34, J9.8 (CS)
DISP_DB0: J1.22, J9.17 (DB0)
DISP_DB1: J1.23, J9.18 (DB1)
DISP_DB2: J1.11, J9.19 (DB2)
DISP_DB3: J1.10, J9.20 (DB3)
DISP_DB4: J1.1, J9.21 (DB4)
DISP_DB5: J1.2, J9.22 (DB5)
DISP_DB6: J1.3, J9.23 (DB6)
DISP_DB7: J1.4, J9.24 (DB7)
DISP_DB8: J1.5, J9.25 (DB8)
DISP_DB9: J1.6, J9.26 (DB9)
DISP_DB10: J1.7, J9.27 (DB10)
DISP_DB11: J1.8, J9.28 (DB11)
DISP_DB12: J1.9, J9.29 (DB12)
DISP_DB13: J1.18, J9.30 (DB13)
DISP_DB14: J1.19, J9.31 (DB14)
DISP_DB15: J1.20, J9.32 (DB15)
DISP_DC: J1.21, J9.9 (DC)
DISP_LEDA: J1.39, J9.36 (LEDA)
DISP_LEDK: J1.38, J9.37 (LEDK1), J9.38 (LEDK2), J9.39 (LEDK3), J9.40 (LEDK4)
DISP_RD: J1.36, J9.11 (RD)
DISP_RES: J1.37, J9.7 (RESET)
DISP_WR: J1.35, J9.10 (WR)
GND: J1.49, J1.Z1, J1.Z2, J9.1 (GND), J9.4 (IM2), J9.5 (IM1), J9.12 (VSYNC), J9.13 (HSYNC), J9.14 (ENABLE), J9.15 (DOTCLK), J9.16 (SDA), J9.45 (GND), J9.P1, J9.P2, LED1.3 (GND), LED2.3 (GND), LED3.3 (GND), LED4.3 (GND), LED5.3 (GND), LED6.3 (GND), LED7.3 (GND), LED8.3 (GND), LED9.3 (GND), LED10.3 (GND), LED11.3 (GND), LED12.3 (GND), LED13.3 (GND), LED14.3 (GND), LED15.3 (GND), LED16.3 (GND), LED17.3 (GND), SW1.2, SW1.4, SW2.2, SW2.4, SW3.2, SW3.4, SW4.2, SW4.4, SW5.2, SW5.4, SW6.2, SW6.4, SW7.2, SW7.4, SW8.2, SW8.4, SW9.2, SW9.4, SW10.2, SW10.4, SW11.2, SW11.4, SW12.2, SW12.4, SW13.2, SW13.4, SW14.2, SW14.4, SW15.2, SW15.4, SW16.2, SW16.4, SW17.2, SW17.4, SW18.2, SW18.4, SW19.2, SW19.4, SW20.2, SW20.4, SW21.2, SW21.4, SW22.2, SW22.4, SW23.2, SW23.4, SW24.2, SW24.4, SW25.2, SW25.4, SW27.2, SW27.4, SW29.2, SW29.4, SW31.2, SW31.4, SW33.2, SW33.4, SW34.2, SW34.4, SW35.2, SW35.4, SW36.2, SW36.4, SW37.2, SW37.4, SW38.2, SW38.4, SW39.2, SW39.4, SW40.2, SW40.4, SW41.2, SW41.4, SW42.2, SW42.4, SW43.3, SW43.4, SW44.3, SW44.4, SW45.3, SW45.4
LED_DATA: J1.12, LED6.4 (DI)
unnamed: LED1.4 (DI), LED13.1 (DO)
unnamed: LED1.1 (DO), LED12.4 (DI)
unnamed: LED2.1 (DO), LED7.4 (DI)
unnamed: LED3.1 (DO), LED8.4 (DI)
unnamed: LED4.1 (DO), LED9.4 (DI)
unnamed: LED5.1 (DO), LED10.4 (DI)
unnamed: LED10.1 (DO), LED16.4 (DI)
unnamed: LED6.1 (DO), LED11.4 (DI)
unnamed: LED11.1 (DO), LED17.4 (DI)
unnamed: LED7.1 (DO), LED13.4 (DI)
unnamed: LED8.1 (DO), LED14.4 (DI)
unnamed: LED2.4 (DI), LED14.1 (DO)
unnamed: LED9.1 (DO), LED15.4 (DI)
unnamed: LED3.4 (DI), LED15.1 (DO)
unnamed: LED4.4 (DI), LED16.1 (DO)
unnamed: LED5.4 (DI), LED17.1 (DO)
PB_0: J1.48, SW3.1, SW3.3, SW4.1, SW4.3
PB_1: J1.32, SW7.1, SW7.3, SW8.1, SW8.3
PB_2: J1.31, SW9.1, SW9.3, SW10.1, SW10.3
PB_3: J1.30, SW11.1, SW11.3, SW12.1, SW12.3
PB_4: J1.29, SW13.1, SW13.3, SW14.1, SW14.3
PB_5: J1.28, SW15.1, SW15.3, SW16.1, SW16.3
PB_6: J1.27, SW17.1, SW17.3, SW18.1, SW18.3
PB_7: J1.26, SW19.1, SW19.3, SW20.1, SW20.3
PB_8: J1.25, SW21.1, SW21.3, SW22.1, SW22.3
PB_9: J1.24, SW23.1, SW23.3, SW24.1, SW24.3
PB_CALL: J1.41, SW39.1, SW39.3, SW40.1, SW40.3
PB_DPAD_DOWN: J1.43, SW31.1, SW31.3
PB_DPAD_LEFT: J1.45, SW25.1, SW25.3
PB_DPAD_RIGHT: J1.44, SW29.1, SW29.3
PB_DPAD_SELECT: J1.46, SW33.1, SW33.3, SW34.1, SW34.3
PB_DPAD_UP: J1.42, SW27.1, SW27.3
PB_END_CALL: J1.40, SW41.1, SW41.3, SW42.1, SW42.3
PB_HASH: J1.33, SW5.1, SW5.3, SW6.1, SW6.3
PB_MENU_L: J1.17, SW35.1, SW35.3, SW36.1, SW36.3
PB_MENU_R: J1.16, SW37.1, SW37.3, SW38.1, SW38.3
PB_PWR: J1.15, SW44.1, SW44.2
PB_STAR: J1.47, SW1.1, SW1.3, SW2.1, SW2.3
PB_VOL_DOWN: J1.14, SW45.1, SW45.2
PB_VOL_UP: J1.13, SW43.1, SW43.2
VLED: LED1.2 (VDD), LED2.2 (VDD), LED3.2 (VDD), LED4.2 (VDD), LED5.2 (VDD), LED6.2 (VDD), LED7.2 (VDD), LED8.2 (VDD), LED9.2 (VDD), LED10.2 (VDD), LED11.2 (VDD), LED12.2 (VDD), LED13.2 (VDD), LED14.2 (VDD), LED15.2 (VDD), LED16.2 (VDD), LED17.2 (VDD), R1.1

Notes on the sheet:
D-Pad Buttons
CONFIRM FOOTPRINT PINS
Menu/Call Buttons
Conn 50x
Keypad Buttons
LEDs
Buttons
Side Buttons
Suits: AFR240320A0-2.0INTM
Display


Board: 2 copper layers, 42.8 x 103.7 mm, 61 parts (1 on the bottom side), 67 nets.

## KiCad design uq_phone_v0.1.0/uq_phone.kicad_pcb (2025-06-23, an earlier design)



Board: 4 copper layers, 42.8 x 103.8 mm, 146 parts (17 on the bottom side), 194 nets.

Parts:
C1, C4, C34: 10uF; C_0603_1608Metric
C2, C3, C19, C35, C42, C44, C45, C46, C47, C48, C49: 4.7uF; C_0402_1005Metric
C5: 470pF; C_0402_1005Metric
C6, C11, C37, C38, C39, C41, C43: 1uF; C_0402_1005Metric
C7: 22uF; C_0603_1608Metric
C8: 10pF; C_0402_1005Metric
C9: 10nF; C_0402_1005Metric
C10, C14, C15, C16, C17, C18, C22, C23, C24, C25, C26, C27, C28, C32, C36: 100nF; C_0402_1005Metric
C12, C13: 47uF; C_0805_2012Metric
C20, C21: 2.2uF; C_0402_1005Metric
C29, C30, C31: 22pF; C_0402_1005Metric
C33, C40: 33pF; C_0402_1005Metric
D1: SP0503BAHTG; SOT143
D2: PMEG2010EA; D_SOD-323
FB1, FB2: MPZ2012S221AT000; BEADC2012X105N
J1: USB4105-GF-A; GCT_USB4105-GF-A
J2: BM03B-ACHSS-GAN-TF_LF__SN_; JST_BM03B-ACHSS-GAN-TF_LF__SN_
J3, J4: 20279-001E-03; IPEX_20279-001E-03
J5: 6871XX14022_68715014022; 68715014022
J6: Conn_ARM_SWD_TagConnect_TC2030; Tag-Connect_TC2030-IDC-FP_2x03_P1.27mm_Vertical
J7: Conn_01x02; SolderWire-0.1sqmm_1x02_P3.6mm_D0.4mm_OD1mm
J8: KP15B-6S-SF_800_; HIROSE_KP15B-6S-SF_800_
J10: SJ-3551B-MSMT-TR-67; CUI_SJ-3551B-MSMT-TR-67
J11: Conn_01x02; SolderWire-0.25sqmm_1x02_P4.2mm_D0.65mm_OD1.7mm
L1: 3.3uH; INDC2520X120N
L2: 4.7uH; WE-MAPI_3015
M1: VCDM0834B004L; Motor_8mm
MK1: AMM-3738-B-R; MIC_AMM-3738-B-R
Q1, Q2: MMBT3904LP-7; DFN101X61X53-3N
R1: 270k; R_0402_1005Metric
R2, R4, R11: 100k; R_0402_1005Metric
R3, R38: 2.2k; R_0402_1005Metric
R5, R6, R9: 5.1k; R_0402_1005Metric
R7, R26, R27, R33, R35, R36, R39, R44, R49: 10k; R_0402_1005Metric
R8: 10m; R_0805_2012Metric
R10: 0R; R_0805_2012Metric
R12, R17, R24, R25: 4.7k; R_0402_1005Metric
R13, R18, R45: 47k; R_0402_1005Metric
R14, R15, R16, R19, R20, R21, R22, R28, R29, R37, R40, R41, R42, R43, R46, R47: 0R; R_0603_1608Metric
R30, R31, R32: 22R; R_0402_1005Metric
R34: 3.83R; R_0603_1608Metric
TP1, TP2, TP3, TP4, TP5, TP6, TP7: TestPoint; TestPoint_Pad_D1.5mm
TP8, TP9, TP10, TP11, TP12, TP13, TP14, TP15, TP16: TestPoint; TestPoint_Pad_D1.0mm
U1: MCP73871-2CCI_ML; QFN50P400X400X100-21N
U2: TPS62162DSGR; SON50P200X200X80-9N
U3: BQ27441DRZR-G1A; IC_BQ27441DRZR-G1A
U4: WP SNAP-IN BASE_6000636; SIERRA_WP_SNAP-IN_BASE
U5, U6: TXB0108RGYR; IC_TXB0108RGYR
U7: STM32H733VGTx; LQFP-100_14x14mm_P0.5mm
U8: LSM6DSVTR; LGA14-L_2P59X3P1X0P5_STM
U9: DRV2603RUNR; QFN50P200X200X80-10N
U10: TPD3F303DQDR; SON40P170X135X80-9N
U11: TPD8F003DQDR; SON40P135X330X80-17N
U12: MCP1664T-E/OT; SOT-23-5_OT_MCH
U13: TS3A5018RSVR; QFN40P260X180X55-16N
U14: NAU88C22YG; QFN50P500X500X80-33N

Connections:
+1.8V: C14.1, C15.1, C36.1, R35.2, R45.2, R47.1, TP7.1, U4.45 (VGPIO), U5.2 (VCCA), U5.10 (OE), U6.2 (VCCA), U6.10 (OE), U13.14 (V+)
+3.3V: C7.1, C16.1, C17.1, C19.1, C22.2, C23.2, C24.2, C25.2, C26.2, C27.1, C28.1, C34.1, FB2.2, J5.1, J6.1 (VCC), J8.C4_1 (VDD), L1.2, L2.1, R9.2, R11.2, R24.2, R25.2, R26.2, R27.2, R28.2, R33.2, TP3.1, U2.6 (VOS), U5.19 (VCCB), U6.19 (VCCB), U7.6 (VBAT), U7.11 (VDD), U7.21 (VDDA), U7.27 (VDD), U7.50 (VDD), U7.75 (VDD), U7.100 (VDD), U8.5 (VDD_IO), U8.8 (VDD), U8.12 (CS), U9.7 (VDD), U12.5 (VIN)
+VMOB: C8.1, C9.1, C10.1, C11.1, C12.1, C13.1, R10.1, TP6.1, U4.61 (VBAT_RF), U4.62 (VBAT_RF__1), U4.63 (VBAT_BB), U4.157 (VBAT_RF__2), U4.158 (VBAT_BB__1)
/Mobile/MOB_USB_N: R14.1, U4.12 (USB_D-)
/Mobile/MOB_USB_P: R15.1, U4.13 (USB_D+)
AGND: C41.2, C43.1, C45.2, C47.2, C48.2, C49.2, FB1.2, J10.4, J10.6, MK1.2 (GND), MK1.3 (GND__1), MK1.5 (GND__2), MK1.6_1 (GND__3), MK1.6_2 (GND__4), R39.2, R44.2, TP4.1, U14.24 (VSSSPK), U14.28 (VSSA), U14.33 (EXP)
AUD_BCLK: R41.2, U13.5 (COM2), U14.8 (BCLK)
AUD_IN: R42.2, U13.7 (COM3), U14.9 (ADCOUT)
AUD_OUT: R43.2, U13.10 (COM4), U14.10 (DACIN)
AUD_SCL: U6.3 (A2), U14.16 (SCLK)
AUD_SDA: U6.1 (A1), U14.17 (SDIO)
AUD_SW_H: U6.14 (B6), U7.34 (PB0)
AUD_SW_L: R35.1, U6.7 (A6), U13.15 (IN)
AUD_SYNC: R40.2, U13.2 (COM1), U14.7 (FS)
BAT_THERM: J2.2, U1.5 (THERM)
DISP_BL: U7.46 (PB10), U12.4 (EN)
DISP_CS: J5.17, U7.88 (PD7)
DISP_DB0: J5.29, U7.61 (PD14)
DISP_DB1: J5.28, U7.62 (PD15)
DISP_DB2: J5.40, U7.81 (PD0)
DISP_DB3: J5.41, U7.82 (PD1)
DISP_DB4: J5.50, U7.37 (PE7)
DISP_DB5: J5.49, U7.38 (PE8)
DISP_DB6: J5.48, U7.39 (PE9)
DISP_DB7: J5.47, U7.40 (PE10)
DISP_DB8: J5.46, U7.41 (PE11)
DISP_DB9: J5.45, U7.42 (PE12)
DISP_DB10: J5.44, U7.43 (PE13)
DISP_DB11: J5.43, U7.44 (PE14)
DISP_DB12: J5.42, U7.45 (PE15)
DISP_DB13: J5.33, U7.55 (PD8)
DISP_DB14: J5.32, U7.56 (PD9)
DISP_DB15: J5.31, U7.57 (PD10)
DISP_DC: J5.30, U7.58 (PD11)
DISP_LEDA: C35.1, D2.1 (K), J5.12
DISP_LEDK: J5.13, R34.2, U12.3 (VFB)
DISP_RD: J5.15, U7.85 (PD4)
DISP_RES: J5.14, U7.84 (PD3)
DISP_WR: J5.16, U7.86 (PD5)
FUEL_GPO: R9.1, U3.12 (GPOUT), U7.51 (PB12)
GND: C1.2, C2.2, C3.2, C4.1, C5.2, C6.2, C7.2, C8.2, C9.2, C10.2, C11.2, C12.2, C13.2, C14.2, C15.2, C16.2, C17.2, C18.1, C19.2, C20.2, C21.2, C22.1, C23.1, C24.1, C25.1, C26.1, C27.2, C28.2, C29.2, C30.2, C31.2, C32.2, C33.2, C34.2, C35.2, C36.2, C40.2, C44.2, C46.2, D1.1, FB1.1, J1.A1_B12 (GND), J1.B1_A12 (GND), J1.SH1 (SHELL_GND), J1.SH2 (SHELL_GND), J1.SH3 (SHELL_GND), J1.SH4 (SHELL_GND), J2.1, J3.2, J4.2, J5.2, J5.Z1, J5.Z2, J6.5 (GND), J8.C5_2 (GND), J8.C6_1 (VSS), J8.G1 (GND__1), J8.G2 (GND__2), J8.S1 (SHIELD), J8.S2 (SHIELD__1), J8.S3 (SHIELD__2), J8.S4 (SHIELD__3), J8.S5 (SHIELD__4), J8.S6 (SHIELD__5), J8.S7 (SHIELD__6), J8.S8 (SHIELD__7), J8.S9 (SHIELD__8), J8.S10 (SHIELD__9), Q1.2, Q2.2, R2.1, R3.2, R4.1, R5.1, R6.1, R7.1, R13.1, R18.1, R29.1, R34.1, R36.1, R49.1, TP2.1, U1.10 (VSS__1), U1.11 (VSS), U1.21 (EP), U2.1 (PGND), U2.4 (AGND), U2.5 (FB), U2.9 (EXP), U3.3 (VSS), U3.13 (EXP), U4.30 (GND_1), U4.32 (GND_1__1), U4.37 (GND_1__2), U4.39 (GND_1__3), U4.48 (GND_1__4), U4.50 (GND_1__5), U4.67 (GND_1__6), U4.68 (GND_1__7), U4.69 (GND_1__8), U4.70 (GND_1__9), U4.111 (GND_1__10), U4.113 (GND_1__11), U4.125 (GND_1__12), U4.128 (GND_1__13), U4.136 (GND_1__14), U4.139 (GND_2), U4.167 (GND_2__1), U4.168 (GND_2__2), U4.169 (GND_2__3), U4.170 (GND_2__4), U4.171 (GND_2__5), U4.172 (GND_2__6), U4.173 (GND_2__7), U4.174 (GND_2__8), U4.175 (GND_2__9), U4.176 (GND_2__10), U4.177 (GND_2__11), U4.178 (GND_2__12), U4.179 (GND_2__13), U4.180 (GND_2__14), U4.181 (GND_3), U4.182 (GND_3__1), U4.183 (GND_3__2), U4.184 (GND_3__3), U4.185 (GND_3__4), U4.186 (GND_3__5), U4.187 (GND_3__6), U4.188 (GND_3__7), U4.189 (GND_3__8), U4.190 (GND_3__9), U4.191 (GND_3__10), U4.192 (GND_3__11), U4.193 (GND_3__12), U4.194 (GND_3__13), U4.195 (GND_4), U4.196 (GND_4__1), U4.197 (GND_4__2), U4.198 (GND_4__3), U4.199 (GND_4__4), U4.200 (GND_4__5), U4.201 (GND_4__6), U4.202 (GND_4__7), U4.203 (GND_4__8), U4.204 (GND_4__9), U4.205 (GND_4__10), U4.206 (GND_4__11), U4.207 (GND_4__12), U4.208 (GND_4__13), U4.209 (GND_4__14), U4.210 (GND_5), U4.211 (GND_5__1), U4.212 (GND_5__2), U4.213 (GND_5__3), U4.214 (GND_5__4), U4.215 (GND_5__5), U4.216 (GND_5__6), U4.217 (GND_5__7), U4.218 (GND_5__8), U4.219 (GND_5__9), U4.220 (GND_5__10), U4.221 (GND_5__11), U4.222 (GND_5__12), U4.223 (GND_5__13), U4.224 (GND_5__14), U4.225 (GND_6), U4.226 (GND_6__1), U4.227 (GND_6__2), U4.228 (GND_6__3), U4.229 (GND_6__4), U4.230 (GND_6__5), U4.231 (GND_6__6), U4.232 (GND_6__7), U4.233 (GND_6__8), U4.234 (GND_6__9), U4.P1, U4.P2, U4.P3, U4.P4, U4.P5, U4.P6, U4.P7, U4.P8, U4.P9, U4.P10, U4.P11, U4.P12, U4.P13, U4.P14, U4.P15, U4.P16, U4.P17, U4.P18, U4.P19, U4.P20, U5.11 (GND), U5.21 (EXP), U5.21_1 (EXP__1), U5.21_2 (EXP__2), U5.21_3 (EXP__3), U5.21_4 (EXP__4), U6.11 (GND), U6.21 (EXP), U6.21_1 (EXP__1), U6.21_2 (EXP__2), U6.21_3 (EXP__3), U6.21_4 (EXP__4), U7.10 (VSS), U7.19 (VSSA), U7.26 (VSS), U7.49 (VSS), U7.74 (VSS), U7.99 (VSS), U8.1 (SDO/SA0), U8.2 (SDX), U8.3 (SCX), U8.6 (GND), U8.7 (GND), U9.5 (GND), U9.8 (GND__1), U9.10 (GND__2), U10.9 (GND), U11.17 (GND), U12.2 (GND), U13.6 (GND), U14.12 (VSSD), U14.18 (MODE)
HP_DET: J10.5, R45.1, U6.5 (A4), U14.15 (CSB/GPIO1)
HP_DET_MCU: U6.16 (B4), U7.33 (PC5)
HP_LEFT: C38.1, U14.30 (LHP)
HP_MIC: C37.1, U14.4 (RMICP)
HP_RIGHT: C39.1, U14.29 (RHP)
LED_DATA: J5.39, U7.25 (PA3)
MCP_OUT: C3.1, C4.2, U1.1 (OUT), U1.20 (OUT__1), U2.2 (VIN), U2.3 (EN)
MCP_PG: U1.6 (~PG), U7.52 (PB13)
MCP_STAT1: R27.1, U1.8 (STAT1/*LBO), U7.54 (PB15)
MCP_STAT2: R26.1, U1.7 (STAT2), U7.53 (PB14)
MCU_AUD_BCLK_H: U6.13 (B7), U7.29 (PA5)
MCU_AUD_BCLK_L: U6.8 (A7), U13.3 (NC2)
MCU_AUD_OUT_L: U6.9 (A8), U13.12 (NC4)
MCU_AUD_OUT_L_H: U6.12 (B8), U7.31 (PA7)
MCU_AUD_SYNC_H: U6.15 (B5), U7.28 (PA4)
MCU_AUD_SYNC_L: U6.6 (A5), U13.16 (NC1)
MCU_CTS: U5.14 (B6), U7.70 (PA11)
MCU_DCD: U5.18 (B2), U7.59 (PD12)
MCU_DSR: U5.20 (B1), U7.67 (PA8)
MCU_DTR: U5.17 (B3), U7.60 (PD13)
MCU_RI: U5.12 (B8), U7.63 (PC6)
MCU_RTS: U5.13 (B7), U7.71 (PA12)
MCU_RXD: U5.16 (B4), U7.69 (PA10)
MCU_TXD: U5.15 (B5), U7.68 (PA9)
MIC_BIAS: C45.1, MK1.4 (VDD), R38.2, U14.32 (MICBIAS)
MIC_GND: C43.2, U14.2 (LMICN)
MIC_OUT: C42.2, U14.1 (LMICP)
MOB_AUD_BCLK: R41.1, U4.36 (PCM_CLK/I2S_CLK), U13.4 (NO2)
MOB_AUD_IN: R42.1, U4.34 (PCM_IN/I2S_IN), U13.8 (NO3)
MOB_AUD_OUT: R43.1, U4.33 (PCM_OUT/I2S_OUT), U13.11 (NO4)
MOB_AUD_SYNC: R40.1, U4.35 (PCM_SYNC/I2S_WS), U13.1 (NO1)
MOB_AUX_ANT: J4.1 (Contact), U4.31 (RF_DIV)
MOB_CTS: R22.2, U5.7 (A6)
MOB_DCD: U4.8 (UART1_DCD), U5.3 (A2)
MOB_DSR: U4.9 (UART1_DSR), U5.1 (A1)
MOB_DTR: U4.7 (UART1_DTR), U5.4 (A3)
MOB_MAIN_ANT: J3.1 (Contact), U4.49 (RF_MAIN)
MOB_PWR: Q1.3, U4.59 (~POWER_ON)
MOB_PWR_CTL: R12.2, U7.36 (PB2)
MOB_RI: U4.2 (UART1_RI), U5.9 (A8)
MOB_RST: Q2.3, U4.11 (~RESET_IN)
MOB_RST_CTL: R17.2, U7.47 (PB11)
MOB_RTS: R20.2, U5.8 (A7)
MOB_RXD: R21.2, U5.5 (A4)
MOB_SYS_CLK: R46.2, U4.22 (SYS_CLK)
MOB_TXD: R19.2, U5.6 (A5)
MOB_WAKE_H: U6.17 (B3), U7.35 (PB1)
MOB_WAKE_L: U4.110 (WAKE_ON_WWAN), U6.4 (A3)
unnamed: C20.1, U7.48 (VCAP)
unnamed: C21.1, U7.73 (VCAP)
unnamed: C37.2, R37.1, R38.1
unnamed: C38.2, J10.2, R39.1
unnamed: C39.2, J10.3, R44.1
unnamed: D2.2 (A), L2.2, U12.1 (SW)
unnamed: J1.A5 (CC1), R6.2
unnamed: J1.B5 (CC2), R5.2
unnamed: J7.1, U9.9 (OUT_P)
unnamed: J7.2, U9.6 (OUT_M)
unnamed: J8.C2_1 (CD/DATA3), U11.15 (CH2_OUT)
unnamed: J8.C5_1 (CLK), U11.13 (CH4_OUT)
unnamed: J8.C3_1 (CMD), U11.14 (CH3_OUT)
unnamed: J8.C7_1 (DAT0), U11.11 (CH6_OUT)
unnamed: J8.C8_1 (DAT1), U11.10 (CH7_OUT)
unnamed: J8.C1_1 (DAT2), U11.16 (CH1_OUT)
unnamed: J8.C3_2 (CLK_2), U10.2 (CLK_OUT)
unnamed: J8.C7_2 (I/O), U10.3 (DATA2_OUT)
unnamed: J8.C2_2 (RST), U10.1 (DATA1_OUT)
unnamed: J10.1, R37.2
unnamed: C42.1, MK1.1 (OUTPUT)
unnamed: Q1.1, R12.1, R13.2
unnamed: Q2.1, R17.1, R18.2
unnamed: R3.1, U1.13 (PROG1)
unnamed: R4.2, U1.12 (PROG3)
unnamed: R1.1, R2.2, U1.2 (VPCC)
unnamed: R11.1, U2.8 (PG)
unnamed: L1.1, U2.7 (SW)
unnamed: C6.1, J2.3, R8.1, U3.6 (BAT), U3.8 (SRP)
unnamed: R7.2, U3.10 (BIN)
unnamed: C5.1, U3.5 (VDD)
unnamed: TP10.1, U4.236 (J1)
unnamed: TP11.1, U4.237 (J2)
unnamed: TP12.1, U4.238 (J3)
unnamed: TP13.1, U4.239 (J4)
unnamed: TP14.1, U4.240 (J5)
unnamed: TP15.1, U4.241 (J6)
unnamed: TP16.1, U4.242 (J7)
unnamed: TP8.1, U4.47 (TP1_BOOTPIN)
unnamed: TP9.1, U4.60 (TX_ON)
unnamed: R22.1, U4.4 (UART1_CTS)
unnamed: R20.1, U4.3 (UART1_RTS)
unnamed: R21.1, U4.6 (UART1_RX)
unnamed: R19.1, U4.5 (UART1_TX)
unnamed: R16.1, U4.16 (USB_VBUS)
unnamed: R49.2, U7.94 (BOOT0)
unnamed: R28.1, R29.2, U9.3 (LRA/~ERM)
unnamed: R32.1, U10.7 (CLK_IN)
unnamed: R31.1, U10.8 (DATA1_IN)
unnamed: R30.1, U10.6 (DATA2_IN)
unnamed: J8.D_T_1, U11.12 (CH5_OUT)
unnamed: R36.2, U13.13 (~EN)
unnamed: C40.1, R46.1, U14.11 (MCLK)
unnamed: C41.1, U14.5 (RMICN)
unnamed: C47.1, C49.1, FB2.1, U14.26 (VDDSPK), U14.31 (VDDA)
unnamed: C44.1, C46.1, R47.2, U14.13 (VDDC), U14.14 (VDDB)
unnamed: C48.1, U14.27 (VREF)
PB_0: J5.3, U7.98 (PE1)
PB_1: J5.19, U7.2 (PE3)
PB_2: J5.20, U7.3 (PE4)
PB_3: J5.21, U7.4 (PE5)
PB_4: J5.22, U7.5 (PE6)
PB_5: J5.23, U7.7 (PC13)
PB_6: J5.24, U7.8 (PC14)
PB_7: J5.25, U7.9 (PC15)
PB_8: J5.26, U7.12 (PH0)
PB_9: J5.27, U7.13 (PH1)
PB_CALL: J5.10, U7.87 (PD6)
PB_DPAD_DOWN: J5.8, U7.90 (PB4(NJTRST))
PB_DPAD_LEFT: J5.6, U7.92 (PB6)
PB_DPAD_RIGHT: J5.7, U7.91 (PB5)
PB_DPAD_SELECT: J5.5, U7.93 (PB7)
PB_DPAD_UP: J5.9, U7.89 (PB3(JTDO)
PB_END_CALL: J5.11, U7.77 (PA15(JTDI))
PB_HASH: J5.18, U7.1 (PE2)
PB_MENU_L: J5.34, U7.15 (PC0)
PB_MENU_R: J5.35, U7.16 (PC1)
PB_PWR: J5.36, U7.22 (PA0)
PB_STAR: J5.4, U7.97 (PE0)
PB_VOL_DOWN: J5.37, U7.23 (PA1)
PB_VOL_UP: J5.38, U7.24 (PA2)
RST: C18.2, J6.3 (~RESET), U7.14 (NRST)
SCL: R24.1, U3.2 (SCL), U6.18 (B2), U7.95 (PB8), U8.13 (SCL)
SDA: R25.1, U3.1 (SDA), U6.20 (B1), U7.96 (PB9), U8.14 (SDA)
SIM_CLK: C29.1, R32.2, U4.28 (UIM1_DATA)
SIM_DATA: C31.1, R30.2, U4.27 (UIM1_CLK)
SIM_RST: C30.1, R31.2, U4.29 (~UIM1_RESET)
SIM_VDD: C32.1, C33.1, J8.C1_2 (VCC), U4.26 (UIM1_VCC), U10.5 (VCC)
SPEAKER_N: J11.2, U14.25 (LSPKOUT)
SPEAKER_P: J11.1, U14.23 (RSPKOUT)
SWCLK: J6.4 (SWCLK), U7.76 (PA14(JTCK)
SWDIO: J6.2 (SWDIO), U7.72 (PA13(JTMS)
USB_N: D1.3, J1.A7 (DN1), J1.B7 (DN2), R14.2
USB_P: D1.4, J1.A6 (DP1), J1.B6 (DP2), R15.2
VBAT: C2.1, R8.2, R10.2, TP5.1, U1.14 (VBAT__1), U1.15 (VBAT), U1.16 (VBAT_SENSE), U3.7 (SRN)
VIB_EN: U7.32 (PC4), U9.1 (EN)
VIB_PWM: U7.30 (PA6), U9.2 (PWM)
VUSB: C1.1, D1.2, J1.A4_B9 (VBUS), J1.B4_A9 (VBUS), R1.2, R16.2, TP1.1, U1.3 (SEL), U1.4 (PROG2), U1.9 (~TE), U1.17 (CE), U1.18 (IN), U1.19 (IN__1)
uSD_CLK: U7.80 (PC12), U11.4 (CH4_IN)
uSD_CMD: U7.83 (PD2), U11.3 (CH3_IN)
uSD_DAT0: U7.65 (PC8), U11.6 (CH6_IN)
uSD_DAT1: U7.66 (PC9), U11.7 (CH7_IN)
uSD_DAT2: U7.78 (PC10), U11.1 (CH1_IN)
uSD_DAT3: U7.79 (PC11), U11.2 (CH2_IN)
uSD_DET: R33.1, U7.64 (PC7), U11.5 (CH5_IN)

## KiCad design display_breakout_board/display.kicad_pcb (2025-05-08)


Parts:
C1: 10uF; C_0603_1608Metric
C2: 4.7uF; C_0402_1005Metric
D1: PMEG2010EA; D_SOD-323
J1: 541324562; CON_541324562_MOL; MANUFACTURER_PART_NUMBER 541324562; DigiKey_Part_Number WM8850TR-ND
J3: Conn_02x12_Odd_Even; PinSocket_2x12_P2.54mm_Vertical
L1: 4.7uH; WE-MAPI_3015; DigiKey_Part_Number 732-4866-2-ND
R1: 3.83R; R_0603_1608Metric
U1: MCP1664T-E/OT; SOT-23-5_OT_MCH

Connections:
+3.3V: C1.1, J1.2 (VCI), J1.3 (IOVCC), J1.6 (IM0), J3.1, L1.1, U1.5 (VIN); also elsewhere on the board
DISP_BL: J3.23, U1.4 (EN)
DISP_CS: J1.8 (CS), J3.6; also elsewhere on the board
DISP_DB0: J1.17 (DB0), J3.14; also elsewhere on the board
DISP_DB1: J1.18 (DB1), J3.16; also elsewhere on the board
DISP_DB2: J1.19 (DB2), J3.18; also elsewhere on the board
DISP_DB3: J1.20 (DB3), J3.20; also elsewhere on the board
DISP_DB4: J1.21 (DB4), J3.22; also elsewhere on the board
DISP_DB5: J1.22 (DB5), J3.24; also elsewhere on the board
DISP_DB6: J1.23 (DB6), J3.3; also elsewhere on the board
DISP_DB7: J1.24 (DB7), J3.5; also elsewhere on the board
DISP_DB8: J1.25 (DB8), J3.7; also elsewhere on the board
DISP_DB9: J1.26 (DB9), J3.9; also elsewhere on the board
DISP_DB10: J1.27 (DB10), J3.11; also elsewhere on the board
DISP_DB11: J1.28 (DB11), J3.13; also elsewhere on the board
DISP_DB12: J1.29 (DB12), J3.15; also elsewhere on the board
DISP_DB13: J1.30 (DB13), J3.17; also elsewhere on the board
DISP_DB14: J1.31 (DB14), J3.19; also elsewhere on the board
DISP_DB15: J1.32 (DB15), J3.21; also elsewhere on the board
DISP_DC: J1.9 (DC), J3.8; also elsewhere on the board
DISP_LEDA: C2.1, D1.1 (K), J1.36 (LEDA); also elsewhere on the board
DISP_LEDK: J1.37 (LEDK1), J1.38 (LEDK2), J1.39 (LEDK3), J1.40 (LEDK4), R1.2, U1.3 (VFB); also elsewhere on the board
DISP_RD: J1.11 (RD), J3.12; also elsewhere on the board
DISP_RES: J1.7 (RESET), J3.4; also elsewhere on the board
DISP_WR: J1.10 (WR), J3.10; also elsewhere on the board
GND: C1.2, C2.2, J1.1 (GND), J1.4 (IM2), J1.5 (IM1), J1.12 (VSYNC), J1.13 (HSYNC), J1.14 (ENABLE), J1.15 (DOTCLK), J1.16 (SDA), J1.45 (GND), J1.P1, J1.P2, J3.2, R1.1, U1.2 (GND); also elsewhere on the board
unnamed: D1.2 (A), L1.2, U1.1 (SW)

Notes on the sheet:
Backlight Driver
CONFIRM FOOTPRINT PINS
Display
Suits: AFR240320A0-2.0INTM
Iout = 0.3/R 3.83R -> 78mA


Board: 2 copper layers, 26.0 x 34.0 mm, 9 parts (1 on the bottom side), 27 nets.

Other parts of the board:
J2: 541324562; CON_541324562_MOL

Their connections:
+3.3V: J2.40 (LEDK4), J2.43 (XL(NC)), J2.44 (YD(NC)); also elsewhere on the board
DISP_CS: J2.38 (LEDK2); also elsewhere on the board
DISP_DB0: J2.29 (DB12); also elsewhere on the board
DISP_DB1: J2.28 (DB11); also elsewhere on the board
DISP_DB2: J2.27 (DB10); also elsewhere on the board
DISP_DB3: J2.26 (DB9); also elsewhere on the board
DISP_DB4: J2.25 (DB8); also elsewhere on the board
DISP_DB5: J2.24 (DB7); also elsewhere on the board
DISP_DB6: J2.23 (DB6); also elsewhere on the board
DISP_DB7: J2.22 (DB5); also elsewhere on the board
DISP_DB8: J2.21 (DB4); also elsewhere on the board
DISP_DB9: J2.20 (DB3); also elsewhere on the board
DISP_DB10: J2.19 (DB2); also elsewhere on the board
DISP_DB11: J2.18 (DB1); also elsewhere on the board
DISP_DB12: J2.17 (DB0); also elsewhere on the board
DISP_DB13: J2.16 (SDA); also elsewhere on the board
DISP_DB14: J2.15 (DOTCLK); also elsewhere on the board
DISP_DB15: J2.14 (ENABLE); also elsewhere on the board
DISP_DC: J2.37 (LEDK1); also elsewhere on the board
DISP_LEDA: J2.10 (WR); also elsewhere on the board
DISP_LEDK: J2.6 (IM0), J2.7 (RESET), J2.8 (CS), J2.9 (DC); also elsewhere on the board
DISP_RD: J2.35 (SDO); also elsewhere on the board
DISP_RES: J2.39 (LEDK3); also elsewhere on the board
DISP_WR: J2.36 (LEDA); also elsewhere on the board
GND: J2.1 (GND), J2.30 (DB13), J2.31 (DB14), J2.32 (DB15), J2.33 (DB16), J2.34 (DB17), J2.41 (XR(NC)), J2.42 (YU(NC)), J2.45 (GND), J2.P1, J2.P2; also elsewhere on the board

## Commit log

2025-04-03 Upload Initial Files
    [audio.kicad_sch, mcu.kicad_sch, mobile.kicad_sch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]
2025-04-08 Update LCD, Add Programer, Shrink Footprints
    [audio.kicad_sch, mcu.kicad_sch, mobile.kicad_sch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]
2025-04-09 Shrink More footprints, rearragment of PCB
    [audio.kicad_sch, mcu.kicad_sch, mobile.kicad_sch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]
2025-04-11 Add display board
    [display.kicad_pcb, display.kicad_sch]
2025-04-11 Update Display Board
    [display.kicad_pcb]
2025-04-11 Update PCB, minor changes
    [audio.kicad_sch, mcu.kicad_sch, mobile.kicad_sch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]
2025-04-13 Minor changes to display
    [display.kicad_pcb]
2025-04-13 Changed SIM/uSD port & adjust routing
    [audio.kicad_sch, mobile.kicad_sch, uq_phone.kicad_pcb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]
2025-04-15 Update display
    [display.kicad_pcb, uq_phone.kicad_pcb]
2025-04-15 Arrange PCB
    [audio.kicad_sch, mcu.kicad_sch, uq_phone.kicad_pcb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]
2025-04-15 Add gerbers
    [display-B_Cu.gbr, display-B_Mask.gbr, display-B_Silkscreen.gbr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]
2025-04-18 Add LEDs, Inital Buttons
    [audio.kicad_sch, display.kicad_pcb, keypad.kicad_sch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]
2025-04-19 Routing Init
    [audio.kicad_sch, keypad.kicad_sch, mcu.kicad_sch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]
2025-04-20 Update routing
    [mcu.kicad_sch, uq_phone.kicad_pcb, user_io.kicad_sch]
2025-04-20 Update to Kicad 9.0, Add 3d Models
    [audio.kicad_sch, keypad.kicad_sch, mcu.kicad_sch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]
2025-04-22 Update pcb and remove Stm32 profile
    [keypad.kicad_sch, mobile.kicad_sch, power.kicad_sch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]
2025-04-23 Update Keypad
    [keypad.kicad_sch, mcu.kicad_sch, uq_phone.kicad_pcb]
2025-04-26 Add Front Pannel Suboard and connector
    [front_board.kicad_pcb, front_board.kicad_sch, keypad.kicad_sch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]
2025-04-26 move button outlines to silkscreen
    [front_board.kicad_pcb]
2025-05-05 Change MCU to h733VG
    [mcu.kicad_sch, uq_phone.kicad_pcb]
2025-05-05 Swap RX TX
    [mcu.kicad_sch, mobile.kicad_sch, power.kicad_sch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]
2025-05-08 Clean up and add DNP
    [audio.kicad_sch, display.kicad_pcb, display.kicad_sch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]
2025-05-20 Minor changes
    [mcu.kicad_sch, mobile.kicad_sch, uq_phone.kicad_pcb]
2025-05-26 Update Various Connectors
    [audio.kicad_sch, front_board.kicad_pcb, front_board.kicad_sch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]
2025-05-27 Generate Early production outputs
    [audio.kicad_sch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]
2025-05-27 Fix outputs
    [front_board-B_Cu.gbl, front_board-B_Mask.gbs, front_board-B_Paste.gbp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]
2025-05-29 Update folder structure
    [audio.kicad_sch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]
2025-06-23 Clean repo
    [audio.kicad_sch, front_board.kicad_pcb, front_board.kicad_sch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]
2025-06-29 Add more footprints, reduce sizes
    [audio.kicad_sch, keypad.kicad_sch, mcu.kicad_sch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]
2025-06-30 Various Changes to footprints and components
    [audio.kicad_sch, keypad.kicad_sch, mcu.kicad_sch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]
2025-07-13 Minor Changes - new display
    [audio.kicad_sch, mcu.kicad_sch, mobile.kicad_sch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]
2025-07-17 New HP jack, move stuff out for new arrangement
    [audio.kicad_sch, mcu.kicad_sch, power.kicad_sch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]
2025-08-01 New Layout
    [mcu.kicad_sch, mobile.kicad_sch, power.kicad_sch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]
2025-08-06 Update layout and BL control
    [mobile.kicad_sch, mobile_old.kicad_sch, uq_phone.kicad_pcb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]
2025-08-07 Several Hours of Routing
    [mcu.kicad_sch, mobile.kicad_sch, uq_phone.kicad_pcb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]
2025-08-08 More routing and placements
    [keypad.kicad_sch, mcu.kicad_sch, mobile.kicad_sch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]
2025-08-09 Another day of routing and adding components
    [audio.kicad_sch, keypad.kicad_sch, mobile.kicad_sch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]
2025-08-10 More routing and moving cellular to new project
    [audio.kicad_sch, keypad.kicad_sch, mcu.kicad_sch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]
2025-08-10 Most routing complete
    [mcu.kicad_sch, uq_phone.kicad_pcb]
2025-08-12 More roting and vias
    [mcu.kicad_sch, uq_phone_cellular.kicad_pcb]
2025-08-15 DRC and routing fixing
    [mcu.kicad_sch, mobile.kicad_sch, power.kicad_sch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]
2025-08-17 New HP jack and circuit
    [audio.kicad_sch, keypad.kicad_sch, power.kicad_sch]
2025-08-20 Restructure, route and add flex pcb
    [audio.kicad_sch, mobile.kicad_sch, power.kicad_sch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]
2025-08-21 New logic level shifters
    [audio.kicad_sch, keypad.kicad_sch, mcu.kicad_sch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]
2025-08-21 Add GNSS antenna for sag
    [mobile.kicad_sch, power.kicad_sch, uq_phone_cellular.kicad_pcb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]
2025-08-22 Fixed display pinout
    [audio.kicad_sch, mcu.kicad_sch, mobile.kicad_sch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]
2025-08-25 Routing improvements
    [audio.kicad_sch, uq_phone_cellular.kicad_pcb]
2025-08-29 Routing Update
    [keypad.kicad_sch, uq_phone_cellular.kicad_pcb]
2025-09-11 Cleaning up adn fixing massive mistake
    [audio.kicad_sch, front_board.kicad_sch, keypad.kicad_sch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]
2025-12-04 minor comments
    [mobile.kicad_sch, power.kicad_sch, user_io.kicad_sch]
